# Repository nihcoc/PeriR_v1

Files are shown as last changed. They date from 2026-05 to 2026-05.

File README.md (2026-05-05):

# PeriR

A custom Software Defined Radio (SDR) carrier board built around the **Xilinx Zynq-7020 SoC** and **Analog Devices AD9364** RF transceiver. The board is designed to run **Kuiper Linux** (Analog Devices' Raspberry Pi OS-based distro) out of the box, with native support for GNU Radio and SDR++ applications.

---

## Overview

This project is inspired by the [FreeSRP](http://electronics.kitchen/misc/freesrp/) open-source SDR by Lukas Lao Beyer and borrows design references from the **FMCOMMS4**, **Zedboard**, **ADRV9364-Z7020**, and **PlutoSDR**.

The goal is a powerful, Linux-capable SDR transceiver with a compact form factor and eventually, a handheld device like the HackRF Portapack.

---

## Key Specifications

| Feature | Detail |
|---|---|
| **SoC / FPGA** | Xilinx Zynq-7020 (ARM Cortex-A9, ~85K LUTs) |
| **RF Transceiver** | Analog Devices AD9364 |
| **Frequency Range** | 70 MHz – 6.0 GHz |
| **Bandwidth** | 200 kHz – 56 MHz |
| **RAM** | 2× 128MB DDR3 (256MB total, Zedboard config) |
| **OS** | Kuiper Linux (Analog Devices / Raspberry Pi OS based) |
| **Primary Storage** | MicroSD card |

---

## Block Diagram

```
Antenna
   │
   ▼
AD9364 RF Transceiver (70MHz–6GHz)
   │  LVDS (max throughput)
   ▼
Zynq-7020 (PS + PL)
   ├── ARM Cortex-A9 (PS) ──► DDR3 RAM, SD Card, USB-OTG, Ethernet, HDMI
```

---

## Hardware Design

### RF Transceiver — AD9364
- **Signalling standard:** LVDS (chosen over CMOS for lower EMI and higher throughput)
- **Interface:** Connected to FPGA Bank 34 (VCCO = 2.5V, `LVDS_25` standard)
- **Balun:** TCM1-63AX+ wideband RF transformer (≤1.8 dB insertion loss @ 6 GHz)
- **Clock:** 40 MHz, 10 pF load capacitance (tested reference from AD)
- **Power rail:** 1.3V via ADP1754ACPZ-1.3-R7 (AD-recommended for stability)
- **TX Power Amp:** PGA-102 (dedicated clean 3.3V supply)

### Zynq-7020 SoC
- **PS Clock:** 33.33 MHz  
- **PL Clock:** 100 MHz (EPSON SG-8018CA oscillator)
- **Boot:** SD Card (primary), QSPI Flash (fallback)
- **Configuration:** Boot mode selectable via header pins/switches
- **RAM interface:** Signal lines terminated at 40 Ω

### Power Architecture

Power sequencing follows **DS187** requirements:
1. VCCPINT (1.0V)
2. VCCPAUX + VCCPLL (1.8V) — simultaneously
3. PS VCCO supplies: VCCOMIO0, VCCOMIO1, VCCO_DDR (3.3V / 1.5V / 0.75V)

| Rail | IC | Current | Usage |
|---|---|---|---|
| 1.0V | TPS62130A | 3A | Zynq VCCINT, VCCBRAM |
| 1.8V | TPS62130A | 3A | Zynq VCCAUX, VCCADC, MIO logic |
| 3.3V | TPS65251-3RHAR (Ch1) | 3A | I/O, SD card, interfaces |
| 2.5V | TPS65251-3RHAR (Ch2) | 2A | FPGA Bank 34 (LVDS) |
| 1.5V | TPS65251-3RHAR (Ch3) | 2A | DDR3 VCCIO |
| 0.75V | MAX1510ETB+ | — | DDR3 VTT termination |
| 1.3V | ADP1754ACPZ-1.3-R7 | — | AD9364 primary supply |
| 5V | External connector | — | Board input power |

> Sequencing is managed using EN (Enable) and PG (Power Good) pins chained between power ICs.
> AD7291BCPZ added for full-board power monitoring.

### Interfaces

| Interface | IC / Notes |
|---|---|
| **HDMI** | ADV7511 transmitter — follows Zedboard design for Kuiper Linux compatibility |
| **USB-OTG** | Standard USB 2.0 OTG with ESD protection |
| **Ethernet** | GbE — backup interface for setup and testing |
| **SD Card** | Level-shifted (1.8V MIO → 3.3V SD logic) |
| **QSPI Flash** | MT25QU128ABA — 128Mb, all data lines active |

## Software

- **OS:** [Kuiper Linux](https://wiki.analog.com/resources/tools-software/linux-software/kuiper-linux) by Analog Devices
- **SDR Applications:** GNU Radio, SDR++
- **FPGA toolchain:** Xilinx Vivado + Analog Devices HDL reference designs
- **Reference HDL:** [Analog Devices HDL](https://github.com/analogdevicesinc/hdl) (FMCOMMS4 / ADRV9364 compatible)

---

## Design References

- [FreeSRP](http://electronics.kitchen/misc/freesrp/) — Lukas Lao Beyer
- Analog Devices FMCOMMS4
- Xilinx Zedboard
- ADRV9364-Z7020
- PlutoSDR
- **Key Datasheets:** UG585, UG933, UG482, UG470, UG483, DS187, AD9364 Reference Manual

---

## Project Status

- [x] Component selection
- [x] Schematic capture
- [x] Footprint assignment
- [x] Schematic verification (round 1)
- [ ] Schematic verification (round 2)
- [ ] PCB layout & routing
- [ ] DFM review
- [ ] Fabrication & assembly
- [ ] Bring-up & firmware development
- [ ] HAT board design

---

*This is a personal learning project. Feedback and suggestions welcome — especially on the RF and LVDS sections!*

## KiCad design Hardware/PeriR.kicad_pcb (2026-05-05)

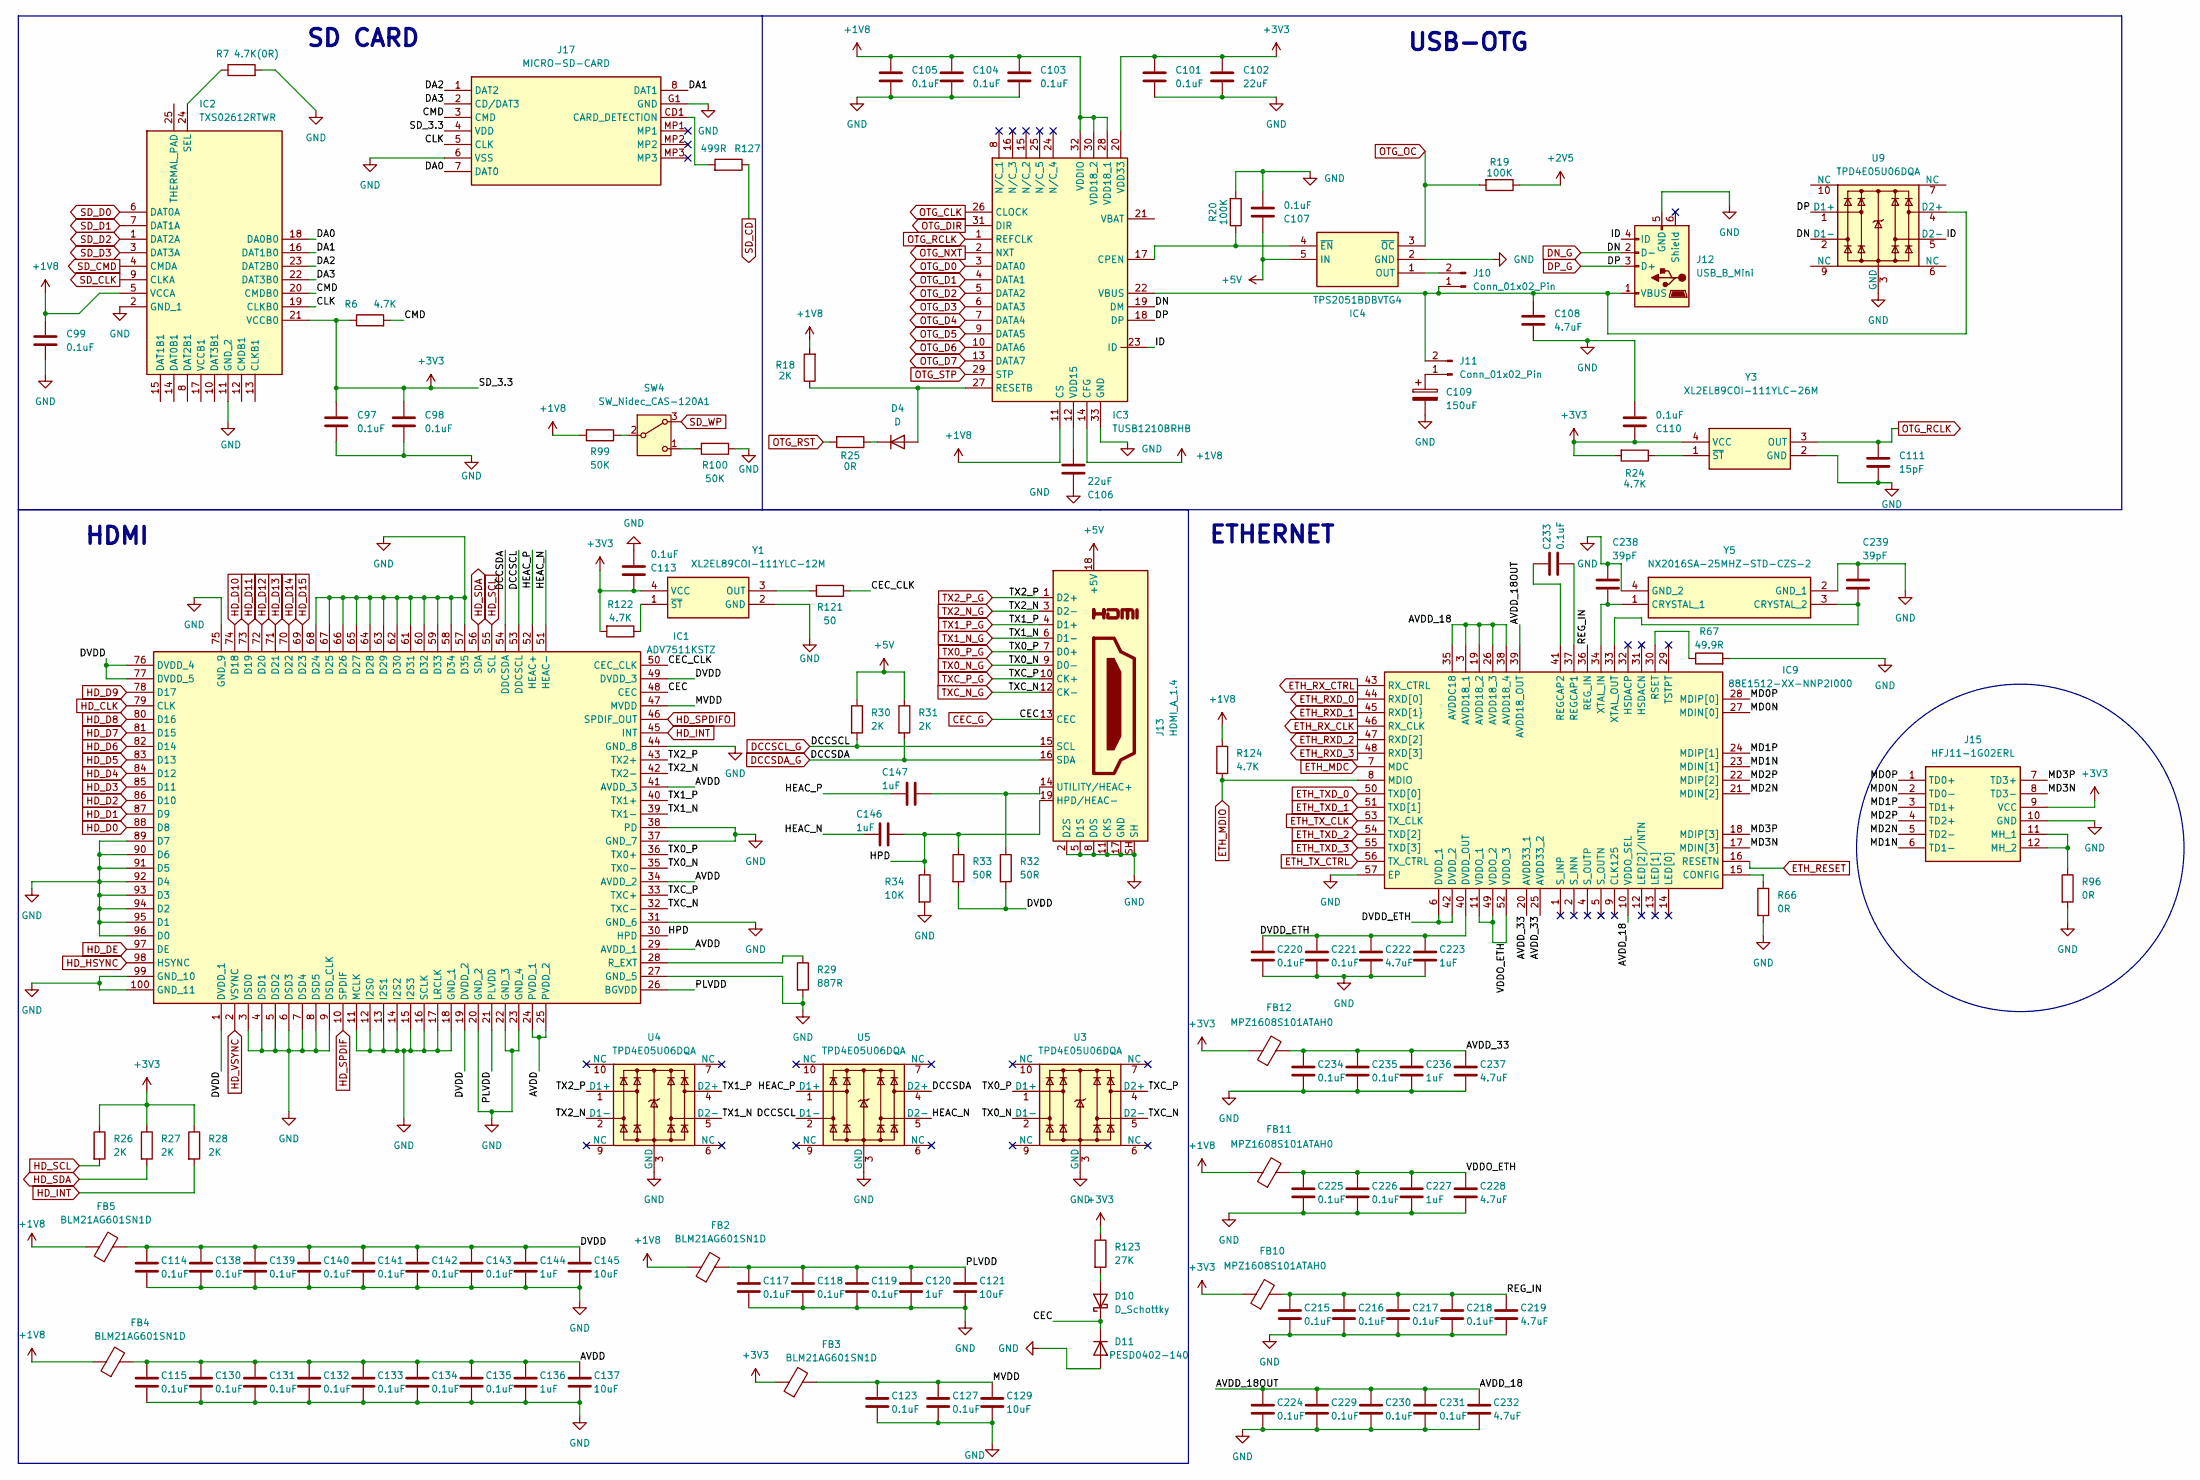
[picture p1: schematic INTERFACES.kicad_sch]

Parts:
C97, C98, C99, C101, C103, C104, C105, C107, C110, C113, C114, C115, C117, C118, C119, C123, C127, C130, C131, C132, C133, C134, C135, C138, C139, C140, C141, C142, C143, C215, C216, C217, C218, C220, C221, C224, C225, C226, C229, C230, C231, C233, C234, C235: 0.1uF; C_0402_1005Metric
C102, C106: 22uF; C_0603_1608Metric
C108, C219, C222, C228, C232, C237: 4.7uF; C_0603_1608Metric
C109: 150uF; CP_EIA-7343-31_Kemet-D
C111: 15pF; C_0201_0603Metric
C120, C136, C144, C146, C147, C223, C227, C236: 1uF; C_0603_1608Metric
C121, C129, C137, C145: 10uF; C_0603_1608Metric
C238, C239: 39pF; C_0201_0603Metric
D4: D; D_0805_2012Metric
D10: D_Schottky; D_0805_2012Metric
D11: PESD0402-140; D_0402_1005Metric
FB2, FB3, FB4, FB5: BLM21AG601SN1D; L_0603_1608Metric
FB10, FB11, FB12: MPZ1608S101ATAH0; L_0603_1608Metric
IC1: ADV7511KSTZ; QFP50P1600X1600X160-100N; Manufacturer_Part_Number ADV7511KSTZ; Mouser Part Number 584-ADV7511KSTZ
IC2: TXS02612RTWR; QFN50P400X400X80-25N-D; Manufacturer_Part_Number TXS02612RTWR; Mouser Part Number 595-TXS02612RTWR
IC3: TUSB1210BRHB; QFN50P500X500X100-33N-D; Manufacturer_Part_Number TUSB1210BRHB; Mouser Part Number 595-TUSB1210BRHB
IC4: TPS2051BDBVTG4; SOT95P280X145-5N; Manufacturer_Part_Number TPS2051BDBVTG4; Mouser Part Number 595-TPS2051BDBVTG4
IC9: 88E1512-XX-NNP2I000; QFN50P800X800X100-57N-D; Manufacturer_Part_Number 88E1512-XX-NNP2I000
J10, J11: Conn_01x02_Pin; PinSocket_1x02_P2.54mm_Vertical
J12: USB_B_Mini; USB_Mini-B_Wuerth_65100516121_Horizontal
J13: HDMI_A_1.4; HDMI_A_Molex_208658-1001_Horizontal
J15: HFJ11-1G02ERL; HFJ111G02ERL; Manufacturer_Part_Number HFJ11-1G02ERL; Mouser Part Number 493-HFJ11-1G02ERL
J17: MICRO-SD-CARD; MICROSDCARD; Manufacturer_Part_Number MICRO-SD-CARD; Mouser Part Number N/A
R6, R24, R122, R124: 4.7K; R_0402_1005Metric
R7: 4.7K(0R); R_0402_1005Metric
R18, R26, R27, R28, R30, R31: 2K; R_0402_1005Metric
R19, R20: 100K; R_0402_1005Metric
R25, R66, R96: 0R; R_0402_1005Metric
R29: 887R; R_0402_1005Metric
R32, R33: 50R; R_0402_1005Metric
R34: 10K; R_0402_1005Metric
R67: 49.9R; R_0402_1005Metric
R99, R100: 50K; R_0402_1005Metric
R121: 50; R_0402_1005Metric
R123: 27K; R_0402_1005Metric
R127: 499R; R_0402_1005Metric
SW4: SW_Nidec_CAS-120A1; Nidec_Copal_CAS-120A
U3, U4, U5, U9: TPD4E05U06DQA; USON-10_2.5x1.0mm_P0.5mm
Y1: XL2EL89COI-111YLC-12M; SG8018CA1000000MTJHSA0; Manufacturer_Part_Number SG-8018CA 100.0000M-TJHSA0
Y3: XL2EL89COI-111YLC-26M; SG8018CA1000000MTJHSA0; Manufacturer_Part_Number SG-8018CA 100.0000M-TJHSA0
Y5: NX2016SA-25MHZ-STD-CZS-2; FA128400000MF20XK; Mouser Part Number 732-FA-12840MF20X-K

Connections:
+1V8: C99.2, C103.2, C104.2, C105.2, FB2.1, FB4.1, FB5.1, FB11.1, IC2.5 (VCCA), IC3.11 (CS), IC3.14 (CFG), IC3.28 (VDD18_1), IC3.30 (VDD18_2), IC3.32 (VDDIO), R18.2, R99.2, R124.1; also elsewhere on the board
+5V: C107.2, IC4.5 (IN), J13.18 (+5V), R30.1, R31.1; also elsewhere on the board
/INTERFACES/AVDD: C115.2, C130.2, C131.2, C132.2, C133.2, C134.2, C135.2, C136.2, C137.2, FB4.2, IC1.24 (PVDD_1), IC1.25 (PVDD_2), IC1.29 (AVDD_1), IC1.34 (AVDD_2), IC1.41 (AVDD_3)
/INTERFACES/AVDD_18: C224.2, C229.2, C230.2, C231.2, C232.2, IC9.3 (AVDD18_1), IC9.10 (VDDO_SEL), IC9.19 (AVDD18_2), IC9.26 (AVDD18_3), IC9.35 (AVDDC18), IC9.38 (AVDD18_4), IC9.39 (AVDD18_OUT)
/INTERFACES/AVDD_33: C234.2, C235.2, C236.2, C237.2, FB12.2, IC9.20 (AVDD33_1), IC9.25 (AVDD33_2)
/INTERFACES/CEC_CLK: IC1.50 (CEC_CLK), R121.1
/INTERFACES/CLK: IC2.19 (CLKB0), J17.5 (CLK)
/INTERFACES/CMD: IC2.20 (CMDB0), J17.3 (CMD), R6.2
/INTERFACES/DA0: IC2.18 (DA0B0), J17.7 (DAT0)
/INTERFACES/DA1: IC2.16 (DAT1B0), J17.8 (DAT1)
/INTERFACES/DA2: IC2.23 (DAT2B0), J17.1 (DAT2)
/INTERFACES/DA3: IC2.22 (DAT3B0), J17.2 (CD/DAT3)
/INTERFACES/DVDD: C114.2, C138.2, C139.2, C140.2, C141.2, C142.2, C143.2, C144.2, C145.2, FB5.2, IC1.1 (DVDD_1), IC1.19 (DVDD_2), IC1.49 (DVDD_3), IC1.76 (DVDD_4), IC1.77 (DVDD_5), R32.2, R33.2
/INTERFACES/DVDD_ETH: C220.2, C221.2, C222.2, C223.2, IC9.6 (DVDD_1), IC9.40 (DVDD_OUT), IC9.42 (DVDD_2)
/INTERFACES/HEAC_N: C146.2, IC1.51 (HEAC-), U5.5 (D2-)
/INTERFACES/HEAC_P: C147.2, IC1.52 (HEAC+), U5.1 (D1+)
/INTERFACES/HPD: C146.1, IC1.30 (HPD), J13.19 (HPD/HEAC-), R33.1, R34.1
/INTERFACES/ID: IC3.23 (ID), J12.4 (ID), U9.5 (D2-)
/INTERFACES/MD0N: IC9.27 (MDIN[0]), J15.2 (TD0-)
/INTERFACES/MD0P: IC9.28 (MDIP[0]), J15.1 (TD0+)
/INTERFACES/MD1N: IC9.23 (MDIN[1]), J15.6 (TD1-)
/INTERFACES/MD1P: IC9.24 (MDIP[1]), J15.3 (TD1+)
/INTERFACES/MD2N: IC9.21 (MDIN[2]), J15.5 (TD2-)
/INTERFACES/MD2P: IC9.22 (MDIP[2]), J15.4 (TD2+)
/INTERFACES/MD3N: IC9.17 (MDIN[3]), J15.8 (TD3-)
/INTERFACES/MD3P: IC9.18 (MDIP[3]), J15.7 (TD3+)
/INTERFACES/MVDD: C123.2, C127.2, C129.2, FB3.2, IC1.47 (MVDD); also elsewhere on the board
/INTERFACES/PLVDD: C117.2, C118.2, C119.2, C120.2, C121.2, FB2.2, IC1.21 (PLVDD), IC1.26 (BGVDD)
/INTERFACES/REG_IN: C215.2, C216.2, C217.2, C218.2, C219.2, FB10.2, IC9.36 (REG_IN)
/INTERFACES/VDDO_ETH: C225.2, C226.2, C227.2, C228.2, FB11.2, IC9.11 (VDDO_1), IC9.49 (VDDO_2), IC9.52 (VDDO_3)
CEC_G: D10.1 (K), D11.1 (K), IC1.48 (CEC), J13.13 (CEC)
DCCSCL_G: IC1.53 (DDCSCL), J13.15 (SCL), R30.2, U5.2 (D1-)
DCCSDA_G: IC1.54 (DDCSDA), J13.16 (SDA), R31.2, U5.4 (D2+)
DN_G: IC3.19 (DM), J12.2 (D-), U9.2 (D1-)
DP_G: IC3.18 (DP), J12.3 (D+), U9.1 (D1+)
ETH_MDC: IC9.7 (MDC); also elsewhere on the board
ETH_MDIO: IC9.8 (MDIO), R124.2; also elsewhere on the board
ETH_RESET: IC9.16 (RESETN); also elsewhere on the board
ETH_RXD_0: IC9.44 (RXD[0]); also elsewhere on the board
ETH_RXD_1: IC9.45 (RXD[1}); also elsewhere on the board
ETH_RXD_2: IC9.47 (RXD[2]); also elsewhere on the board
ETH_RXD_3: IC9.48 (RXD[3]); also elsewhere on the board
ETH_RX_CLK: IC9.46 (RX_CLK); also elsewhere on the board
ETH_RX_CTRL: IC9.43 (RX_CTRL); also elsewhere on the board
ETH_TXD_0: IC9.50 (TXD[0]); also elsewhere on the board
ETH_TXD_1: IC9.51 (TXD[1]); also elsewhere on the board
ETH_TXD_2: IC9.54 (TXD[2]); also elsewhere on the board
ETH_TXD_3: IC9.55 (TXD[3]); also elsewhere on the board
ETH_TX_CLK: IC9.53 (TX_CLK); also elsewhere on the board
ETH_TX_CTRL: IC9.56 (TX_CTRL); also elsewhere on the board
HD_CLK: IC1.79 (CLK); also elsewhere on the board
HD_D0: IC1.88 (D8); also elsewhere on the board
HD_D1: IC1.87 (D9); also elsewhere on the board
HD_D2: IC1.86 (D10); also elsewhere on the board
HD_D3: IC1.85 (D11); also elsewhere on the board
HD_D4: IC1.84 (D12); also elsewhere on the board
HD_D5: IC1.83 (D13); also elsewhere on the board
HD_D6: IC1.82 (D14); also elsewhere on the board
HD_D7: IC1.81 (D15); also elsewhere on the board
HD_D8: IC1.80 (D16); also elsewhere on the board
HD_D9: IC1.78 (D17); also elsewhere on the board
HD_D10: IC1.74 (D18); also elsewhere on the board
HD_D11: IC1.73 (D19); also elsewhere on the board
HD_D12: IC1.72 (D20); also elsewhere on the board
HD_D13: IC1.71 (D21); also elsewhere on the board
HD_D14: IC1.70 (D22); also elsewhere on the board
HD_D15: IC1.69 (D23); also elsewhere on the board
HD_DE: IC1.97 (DE); also elsewhere on the board
HD_HSYNC: IC1.98 (HSYNC); also elsewhere on the board
HD_INT: IC1.45 (INT), R28.2; also elsewhere on the board
HD_SCL: IC1.55 (SCL), R26.2; also elsewhere on the board
HD_SDA: IC1.56 (SDA), R27.2; also elsewhere on the board
HD_SPDIF: IC1.10 (SPDIF); also elsewhere on the board
HD_SPDIFO: IC1.46 (SPDIF_OUT); also elsewhere on the board
HD_VSYNC: IC1.2 (VSYNC); also elsewhere on the board
unnamed: D4.2 (A), IC3.27 (RESETB), R18.1
unnamed: D4.1 (K), R25.1
unnamed: D10.2 (A), R123.2
unnamed: IC1.28 (R_EXT), R29.1
unnamed: IC2.24 (SEL), R7.1
unnamed: IC3.17 (CPEN), IC4.4 (~EN), R20.1
unnamed: C108.1, IC3.22 (VBUS), J10.1, J11.2, J12.1 (VBUS), U9.4 (D2+)
unnamed: C106.1, IC3.12 (VDD15)
unnamed: IC4.1 (OUT), J10.2
unnamed: IC9.15 (CONFIG), R66.1
unnamed: C233.1, IC9.37 (REGCAP1)
unnamed: C233.2, IC9.41 (REGCAP2)
unnamed: IC9.30 (RSET), R67.1
unnamed: C238.1, IC9.34 (XTAL_IN), Y5.1 (CRYSTAL_1)
unnamed: C239.1, IC9.33 (XTAL_OUT), Y5.3 (CRYSTAL_2)
unnamed: C109.1, J11.1
unnamed: C147.1, J13.14 (UTILITY/HEAC+), R32.1
unnamed: J15.11 (MH_1), J15.12 (MH_2), R96.1
unnamed: J17.CD1 (CARD_DETECTION), R127.2
unnamed: R99.1, SW4.2 (B)
unnamed: R100.2, SW4.1 (C)
unnamed: R121.2, Y1.3 (OUT)
unnamed: R122.1, Y1.1 (~ST)
unnamed: R24.1, Y3.1 (~ST)
OTG_CLK: IC3.26 (CLOCK); also elsewhere on the board
OTG_D0: IC3.3 (DATA0); also elsewhere on the board
OTG_D1: IC3.4 (DATA1); also elsewhere on the board
OTG_D2: IC3.5 (DATA2); also elsewhere on the board
OTG_D3: IC3.6 (DATA3); also elsewhere on the board
OTG_D4: IC3.7 (DATA4); also elsewhere on the board
OTG_D5: IC3.9 (DATA5); also elsewhere on the board
OTG_D6: IC3.10 (DATA6); also elsewhere on the board
OTG_D7: IC3.13 (DATA7); also elsewhere on the board
OTG_DIR: IC3.31 (DIR); also elsewhere on the board
OTG_NXT: IC3.2 (NXT); also elsewhere on the board
OTG_OC: IC4.3 (~OC), R19.2; also elsewhere on the board
OTG_RCLK: C111.1, IC3.1 (REFCLK), Y3.3 (OUT)
OTG_RST: R25.2; also elsewhere on the board
OTG_STP: IC3.29 (STP); also elsewhere on the board
SD_CD: R127.1; also elsewhere on the board
SD_CLK: IC2.9 (CLKA); also elsewhere on the board
SD_CMD: IC2.4 (CMDA); also elsewhere on the board
SD_D0: IC2.6 (DAT0A); also elsewhere on the board
SD_D1: IC2.7 (DAT1A); also elsewhere on the board
SD_D2: IC2.1 (DAT2A); also elsewhere on the board
SD_D3: IC2.3 (DAT3A); also elsewhere on the board
SD_WP: SW4.3 (A); also elsewhere on the board
TX0_N_G: IC1.35 (TX0-), J13.9 (D0-), U3.2 (D1-)
TX0_P_G: IC1.36 (TX0+), J13.7 (D0+), U3.1 (D1+)
TX1_N_G: IC1.39 (TX1-), J13.6 (D1-), U4.5 (D2-)
TX1_P_G: IC1.40 (TX1+), J13.4 (D1+), U4.4 (D2+)
TX2_N_G: IC1.42 (TX2-), J13.3 (D2-), U4.2 (D1-)
TX2_P_G: IC1.43 (TX2+), J13.1 (D2+), U4.1 (D1+)
TXC_N_G: IC1.32 (TXC-), J13.12 (CK-), U3.5 (D2-)
TXC_P_G: IC1.33 (TXC+), J13.10 (CK+), U3.4 (D2+)

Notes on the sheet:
SD CARD
USB-OTG
ETHERNET
HDMI

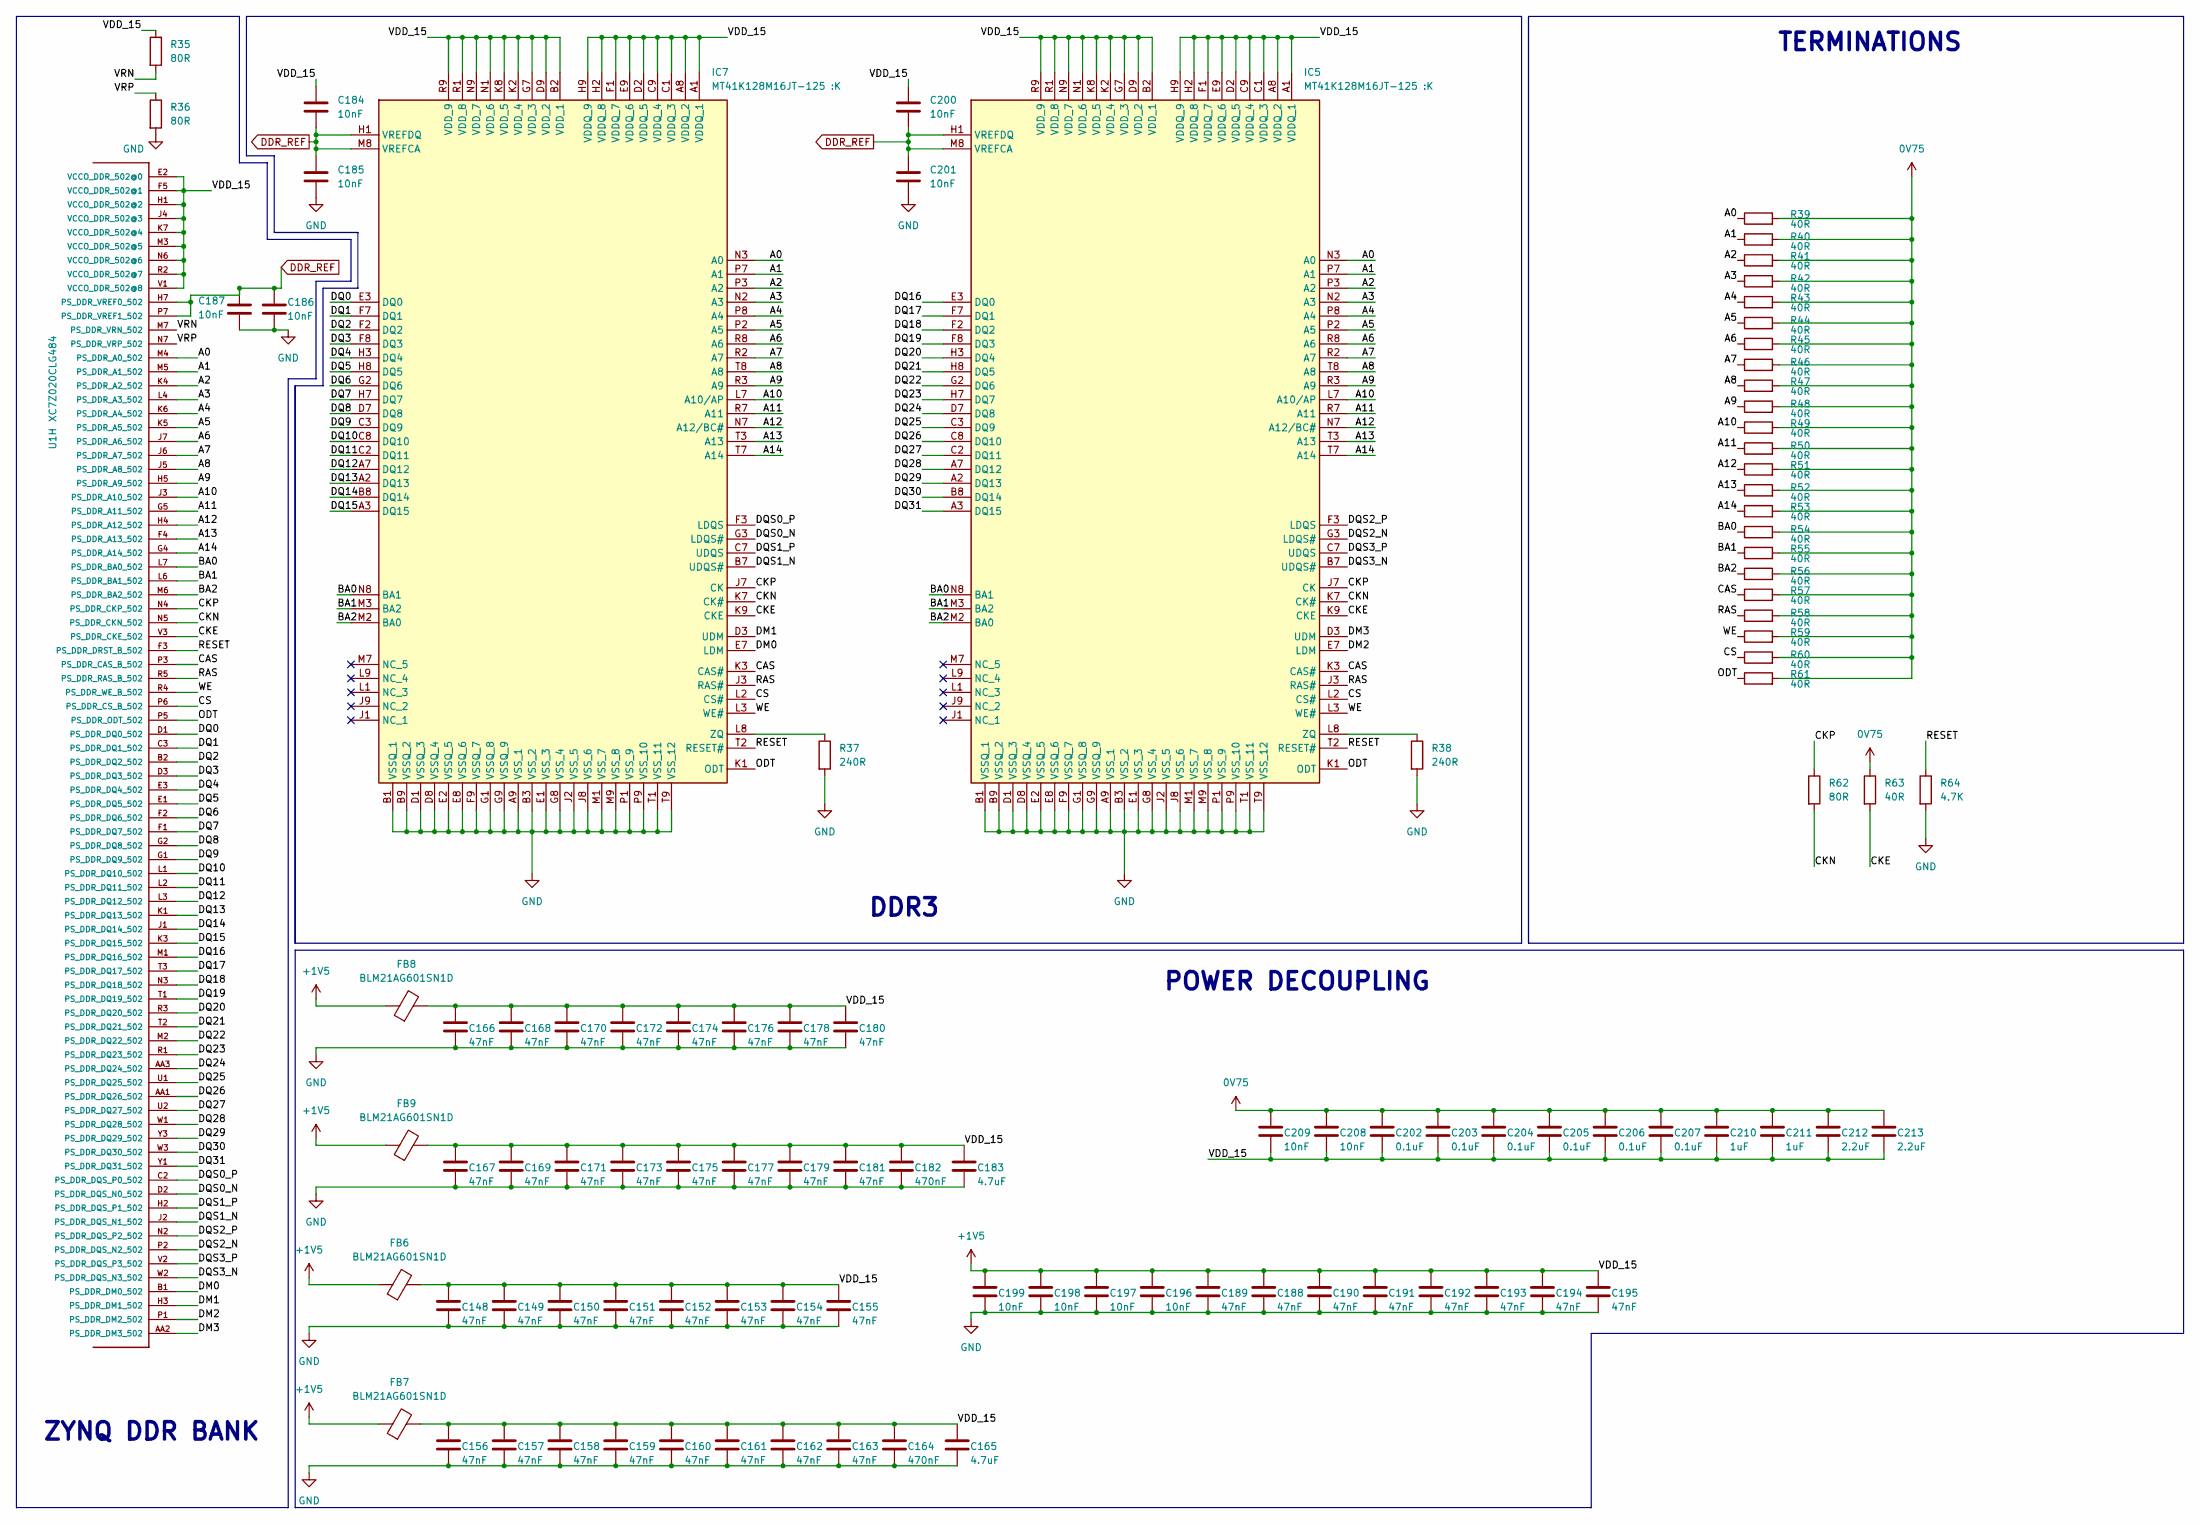
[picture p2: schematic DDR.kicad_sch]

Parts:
C148, C149, C150, C151, C152, C153, C154, C155, C156, C157, C158, C159, C160, C161, C162, C163, C166, C167, C168, C169, C170, C171, C172, C173, C174, C175, C176, C177, C178, C179, C180, C181, C188, C189, C190, C191, C192, C193, C194, C195: 47nF; C_0201_0603Metric
C164: 470nF; C_0402_1005Metric
C165, C183: 4.7uF; C_0603_1608Metric
C182: 470nF; C_0201_0603Metric
C184, C185, C186, C187, C196, C197, C198, C199, C200, C201: 10nF; C_0201_0603Metric
C202, C203, C204, C205, C206, C207: 0.1uF; C_0402_1005Metric
C208, C209: 10nF; C_0603_1608Metric
C210, C211: 1uF; C_0603_1608Metric
C212, C213: 2.2uF; C_0603_1608Metric
FB6, FB7, FB8, FB9: BLM21AG601SN1D; L_0603_1608Metric
IC5, IC7: MT41K128M16JT-125 :K; BGA96C80P9X16_800X1400X120; Manufacturer_Part_Number MT41K128M16JT-125
R35, R36, R62: 80R; R_0402_1005Metric
R37, R38: 240R; R_0402_1005Metric
R39, R40, R41, R42, R43, R44, R45, R46, R47, R48, R49, R50, R51, R52, R53, R54, R55, R56, R57, R58, R59, R60, R61, R63: 40R; R_0402_1005Metric
R64: 4.7K; R_0402_1005Metric
U1: XC7Z020CLG484; CS484

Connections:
0V75: C202.1, C203.1, C204.1, C205.1, C206.1, C207.1, C208.1, C209.1, C210.1, C211.1, C212.1, C213.1, R39.2, R40.2, R41.2, R42.2, R43.2, R44.2, R45.2, R46.2, R47.2, R48.2, R49.2, R50.2, R51.2, R52.2, R53.2, R54.2, R55.2, R56.2, R57.2, R58.2, R59.2, R60.2, R61.2, R63.1; also elsewhere on the board
+1V5: C148.1, C149.1, C150.1, C151.1, C152.1, C153.1, C154.1, C155.1, C156.1, C157.1, C158.1, C159.1, C160.1, C161.1, C162.1, C163.1, C164.1, C165.1, C166.1, C167.1, C168.1, C169.1, C170.1, C171.1, C172.1, C173.1, C174.1, C175.1, C176.1, C177.1, C178.1, C179.1, C180.1, C181.1, C182.1, C183.1, C184.1, C188.1, C189.1, C190.1, C191.1, C192.1, C193.1, C194.1, C195.1, C196.1, C197.1, C198.1, C199.1, C200.1, C202.2, C203.2, C204.2, C205.2, C206.2, C207.2, C208.2, C209.2, C210.2, C211.2, C212.2, C213.2, FB6.1, FB6.2, FB7.1, FB7.2, FB8.1, FB8.2, FB9.1, FB9.2, IC5.A1 (VDDQ_1), IC5.A8 (VDDQ_2), IC5.B2 (VDD_1), IC5.C1 (VDDQ_3), IC5.C9 (VDDQ_4), IC5.D2 (VDDQ_5), IC5.D9 (VDD_2), IC5.E9 (VDDQ_6), IC5.F1 (VDDQ_7), IC5.G7 (VDD_3), IC5.H2 (VDDQ_8), IC5.H9 (VDDQ_9), IC5.K2 (VDD_4), IC5.K8 (VDD_5), IC5.N1 (VDD_6), IC5.N9 (VDD_7), IC5.R1 (VDD_8), IC5.R9 (VDD_9), IC7.A1 (VDDQ_1), IC7.A8 (VDDQ_2), IC7.B2 (VDD_1), IC7.C1 (VDDQ_3), IC7.C9 (VDDQ_4), IC7.D2 (VDDQ_5), IC7.D9 (VDD_2), IC7.E9 (VDDQ_6), IC7.F1 (VDDQ_7), IC7.G7 (VDD_3), IC7.H2 (VDDQ_8), IC7.H9 (VDDQ_9), IC7.K2 (VDD_4), IC7.K8 (VDD_5), IC7.N1 (VDD_6), IC7.N9 (VDD_7), IC7.R1 (VDD_8), IC7.R9 (VDD_9), R35.1, U1.E2 (VCCO_DDR_502@0), U1.F5 (VCCO_DDR_502@1), U1.H1 (VCCO_DDR_502@2), U1.J4 (VCCO_DDR_502@3), U1.K7 (VCCO_DDR_502@4), U1.M3 (VCCO_DDR_502@5), U1.N6 (VCCO_DDR_502@6), U1.R2 (VCCO_DDR_502@7), U1.V1 (VCCO_DDR_502@8); also elsewhere on the board
/DDR/A0: IC5.N3 (A0), IC7.N3 (A0), R39.1, U1.M4 (PS_DDR_A0_502)
/DDR/A1: IC5.P7 (A1), IC7.P7 (A1), R40.1, U1.M5 (PS_DDR_A1_502)
/DDR/A2: IC5.P3 (A2), IC7.P3 (A2), R41.1, U1.K4 (PS_DDR_A2_502)
/DDR/A3: IC5.N2 (A3), IC7.N2 (A3), R42.1, U1.L4 (PS_DDR_A3_502)
/DDR/A4: IC5.P8 (A4), IC7.P8 (A4), R43.1, U1.K6 (PS_DDR_A4_502)
/DDR/A5: IC5.P2 (A5), IC7.P2 (A5), R44.1, U1.K5 (PS_DDR_A5_502)
/DDR/A6: IC5.R8 (A6), IC7.R8 (A6), R45.1, U1.J7 (PS_DDR_A6_502)
/DDR/A7: IC5.R2 (A7), IC7.R2 (A7), R46.1, U1.J6 (PS_DDR_A7_502)
/DDR/A8: IC5.T8 (A8), IC7.T8 (A8), R47.1, U1.J5 (PS_DDR_A8_502)
/DDR/A9: IC5.R3 (A9), IC7.R3 (A9), R48.1, U1.H5 (PS_DDR_A9_502)
/DDR/A10: IC5.L7 (A10/AP), IC7.L7 (A10/AP), R49.1, U1.J3 (PS_DDR_A10_502)
/DDR/A11: IC5.R7 (A11), IC7.R7 (A11), R50.1, U1.G5 (PS_DDR_A11_502)
/DDR/A12: IC5.N7 (A12/BC#), IC7.N7 (A12/BC#), R51.1, U1.H4 (PS_DDR_A12_502)
/DDR/A13: IC5.T3 (A13), IC7.T3 (A13), R52.1, U1.F4 (PS_DDR_A13_502)
/DDR/A14: IC5.T7 (A14), IC7.T7 (A14), R53.1, U1.G4 (PS_DDR_A14_502)
/DDR/BA0: IC5.N8 (BA1), IC7.N8 (BA1), R54.1, U1.L7 (PS_DDR_BA0_502)
/DDR/BA1: IC5.M3 (BA2), IC7.M3 (BA2), R55.1, U1.L6 (PS_DDR_BA1_502)
/DDR/BA2: IC5.M2 (BA0), IC7.M2 (BA0), R56.1, U1.M6 (PS_DDR_BA2_502)
/DDR/CAS: IC5.K3 (CAS#), IC7.K3 (CAS#), R57.1, U1.P3 (PS_DDR_CAS_B_502)
/DDR/CKE: IC5.K9 (CKE), IC7.K9 (CKE), R63.2, U1.V3 (PS_DDR_CKE_502)
/DDR/CKN: IC5.K7 (CK#), IC7.K7 (CK#), R62.2, U1.N5 (PS_DDR_CKN_502)
/DDR/CKP: IC5.J7 (CK), IC7.J7 (CK), R62.1, U1.N4 (PS_DDR_CKP_502)
/DDR/CS: IC5.L2 (CS#), IC7.L2 (CS#), R60.1, U1.P6 (PS_DDR_CS_B_502)
/DDR/DM0: IC7.E7 (LDM), U1.B1 (PS_DDR_DM0_502)
/DDR/DM1: IC7.D3 (UDM), U1.H3 (PS_DDR_DM1_502)
/DDR/DM2: IC5.E7 (LDM), U1.P1 (PS_DDR_DM2_502)
/DDR/DM3: IC5.D3 (UDM), U1.AA2 (PS_DDR_DM3_502)
/DDR/DQ0: IC7.E3 (DQ0), U1.D1 (PS_DDR_DQ0_502)
/DDR/DQ1: IC7.F7 (DQ1), U1.C3 (PS_DDR_DQ1_502)
/DDR/DQ2: IC7.F2 (DQ2), U1.B2 (PS_DDR_DQ2_502)
/DDR/DQ3: IC7.F8 (DQ3), U1.D3 (PS_DDR_DQ3_502)
/DDR/DQ4: IC7.H3 (DQ4), U1.E3 (PS_DDR_DQ4_502)
/DDR/DQ5: IC7.H8 (DQ5), U1.E1 (PS_DDR_DQ5_502)
/DDR/DQ6: IC7.G2 (DQ6), U1.F2 (PS_DDR_DQ6_502)
/DDR/DQ7: IC7.H7 (DQ7), U1.F1 (PS_DDR_DQ7_502)
/DDR/DQ8: IC7.D7 (DQ8), U1.G2 (PS_DDR_DQ8_502)
/DDR/DQ9: IC7.C3 (DQ9), U1.G1 (PS_DDR_DQ9_502)
/DDR/DQ10: IC7.C8 (DQ10), U1.L1 (PS_DDR_DQ10_502)
/DDR/DQ11: IC7.C2 (DQ11), U1.L2 (PS_DDR_DQ11_502)
/DDR/DQ12: IC7.A7 (DQ12), U1.L3 (PS_DDR_DQ12_502)
/DDR/DQ13: IC7.A2 (DQ13), U1.K1 (PS_DDR_DQ13_502)
/DDR/DQ14: IC7.B8 (DQ14), U1.J1 (PS_DDR_DQ14_502)
/DDR/DQ15: IC7.A3 (DQ15), U1.K3 (PS_DDR_DQ15_502)
/DDR/DQ16: IC5.E3 (DQ0), U1.M1 (PS_DDR_DQ16_502)
/DDR/DQ17: IC5.F7 (DQ1), U1.T3 (PS_DDR_DQ17_502)
/DDR/DQ18: IC5.F2 (DQ2), U1.N3 (PS_DDR_DQ18_502)
/DDR/DQ19: IC5.F8 (DQ3), U1.T1 (PS_DDR_DQ19_502)
/DDR/DQ20: IC5.H3 (DQ4), U1.R3 (PS_DDR_DQ20_502)
/DDR/DQ21: IC5.H8 (DQ5), U1.T2 (PS_DDR_DQ21_502)
/DDR/DQ22: IC5.G2 (DQ6), U1.M2 (PS_DDR_DQ22_502)
/DDR/DQ23: IC5.H7 (DQ7), U1.R1 (PS_DDR_DQ23_502)
/DDR/DQ24: IC5.D7 (DQ8), U1.AA3 (PS_DDR_DQ24_502)
/DDR/DQ25: IC5.C3 (DQ9), U1.U1 (PS_DDR_DQ25_502)
/DDR/DQ26: IC5.C8 (DQ10), U1.AA1 (PS_DDR_DQ26_502)
/DDR/DQ27: IC5.C2 (DQ11), U1.U2 (PS_DDR_DQ27_502)
/DDR/DQ28: IC5.A7 (DQ12), U1.W1 (PS_DDR_DQ28_502)
/DDR/DQ29: IC5.A2 (DQ13), U1.Y3 (PS_DDR_DQ29_502)
/DDR/DQ30: IC5.B8 (DQ14), U1.W3 (PS_DDR_DQ30_502)
/DDR/DQ31: IC5.A3 (DQ15), U1.Y1 (PS_DDR_DQ31_502)
/DDR/DQS0_N: IC7.G3 (LDQS#), U1.D2 (PS_DDR_DQS_N0_502)
/DDR/DQS0_P: IC7.F3 (LDQS), U1.C2 (PS_DDR_DQS_P0_502)
/DDR/DQS1_N: IC7.B7 (UDQS#), U1.J2 (PS_DDR_DQS_N1_502)
/DDR/DQS1_P: IC7.C7 (UDQS), U1.H2 (PS_DDR_DQS_P1_502)
/DDR/DQS2_N: IC5.G3 (LDQS#), U1.P2 (PS_DDR_DQS_N2_502)
/DDR/DQS2_P: IC5.F3 (LDQS), U1.N2 (PS_DDR_DQS_P2_502)
/DDR/DQS3_N: IC5.B7 (UDQS#), U1.W2 (PS_DDR_DQS_N3_502)
/DDR/DQS3_P: IC5.C7 (UDQS), U1.V2 (PS_DDR_DQS_P3_502)
/DDR/ODT: IC5.K1 (ODT), IC7.K1 (ODT), R61.1, U1.P5 (PS_DDR_ODT_502)
/DDR/RAS: IC5.J3 (RAS#), IC7.J3 (RAS#), R58.1, U1.R5 (PS_DDR_RAS_B_502)
/DDR/RESET: IC5.T2 (RESET#), IC7.T2 (RESET#), R64.1, U1.F3 (PS_DDR_DRST_B_502)
/DDR/VRN: R35.2, U1.M7 (PS_DDR_VRN_502)
/DDR/VRP: R36.1, U1.N7 (PS_DDR_VRP_502)
/DDR/WE: IC5.L3 (WE#), IC7.L3 (WE#), R59.1, U1.R4 (PS_DDR_WE_B_502)
DDR_REF: C184.2, C185.1, C186.1, C187.1, C200.2, C201.1, IC5.H1 (VREFDQ), IC5.M8 (VREFCA), IC7.H1 (VREFDQ), IC7.M8 (VREFCA), U1.H7 (PS_DDR_VREF0_502), U1.P7 (PS_DDR_VREF1_502); also elsewhere on the board
unnamed: IC5.L8 (ZQ), R38.1
unnamed: IC7.L8 (ZQ), R37.1

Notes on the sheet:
DDR3
POWER DECOUPLING
ZYNQ DDR BANK
TERMINATIONS

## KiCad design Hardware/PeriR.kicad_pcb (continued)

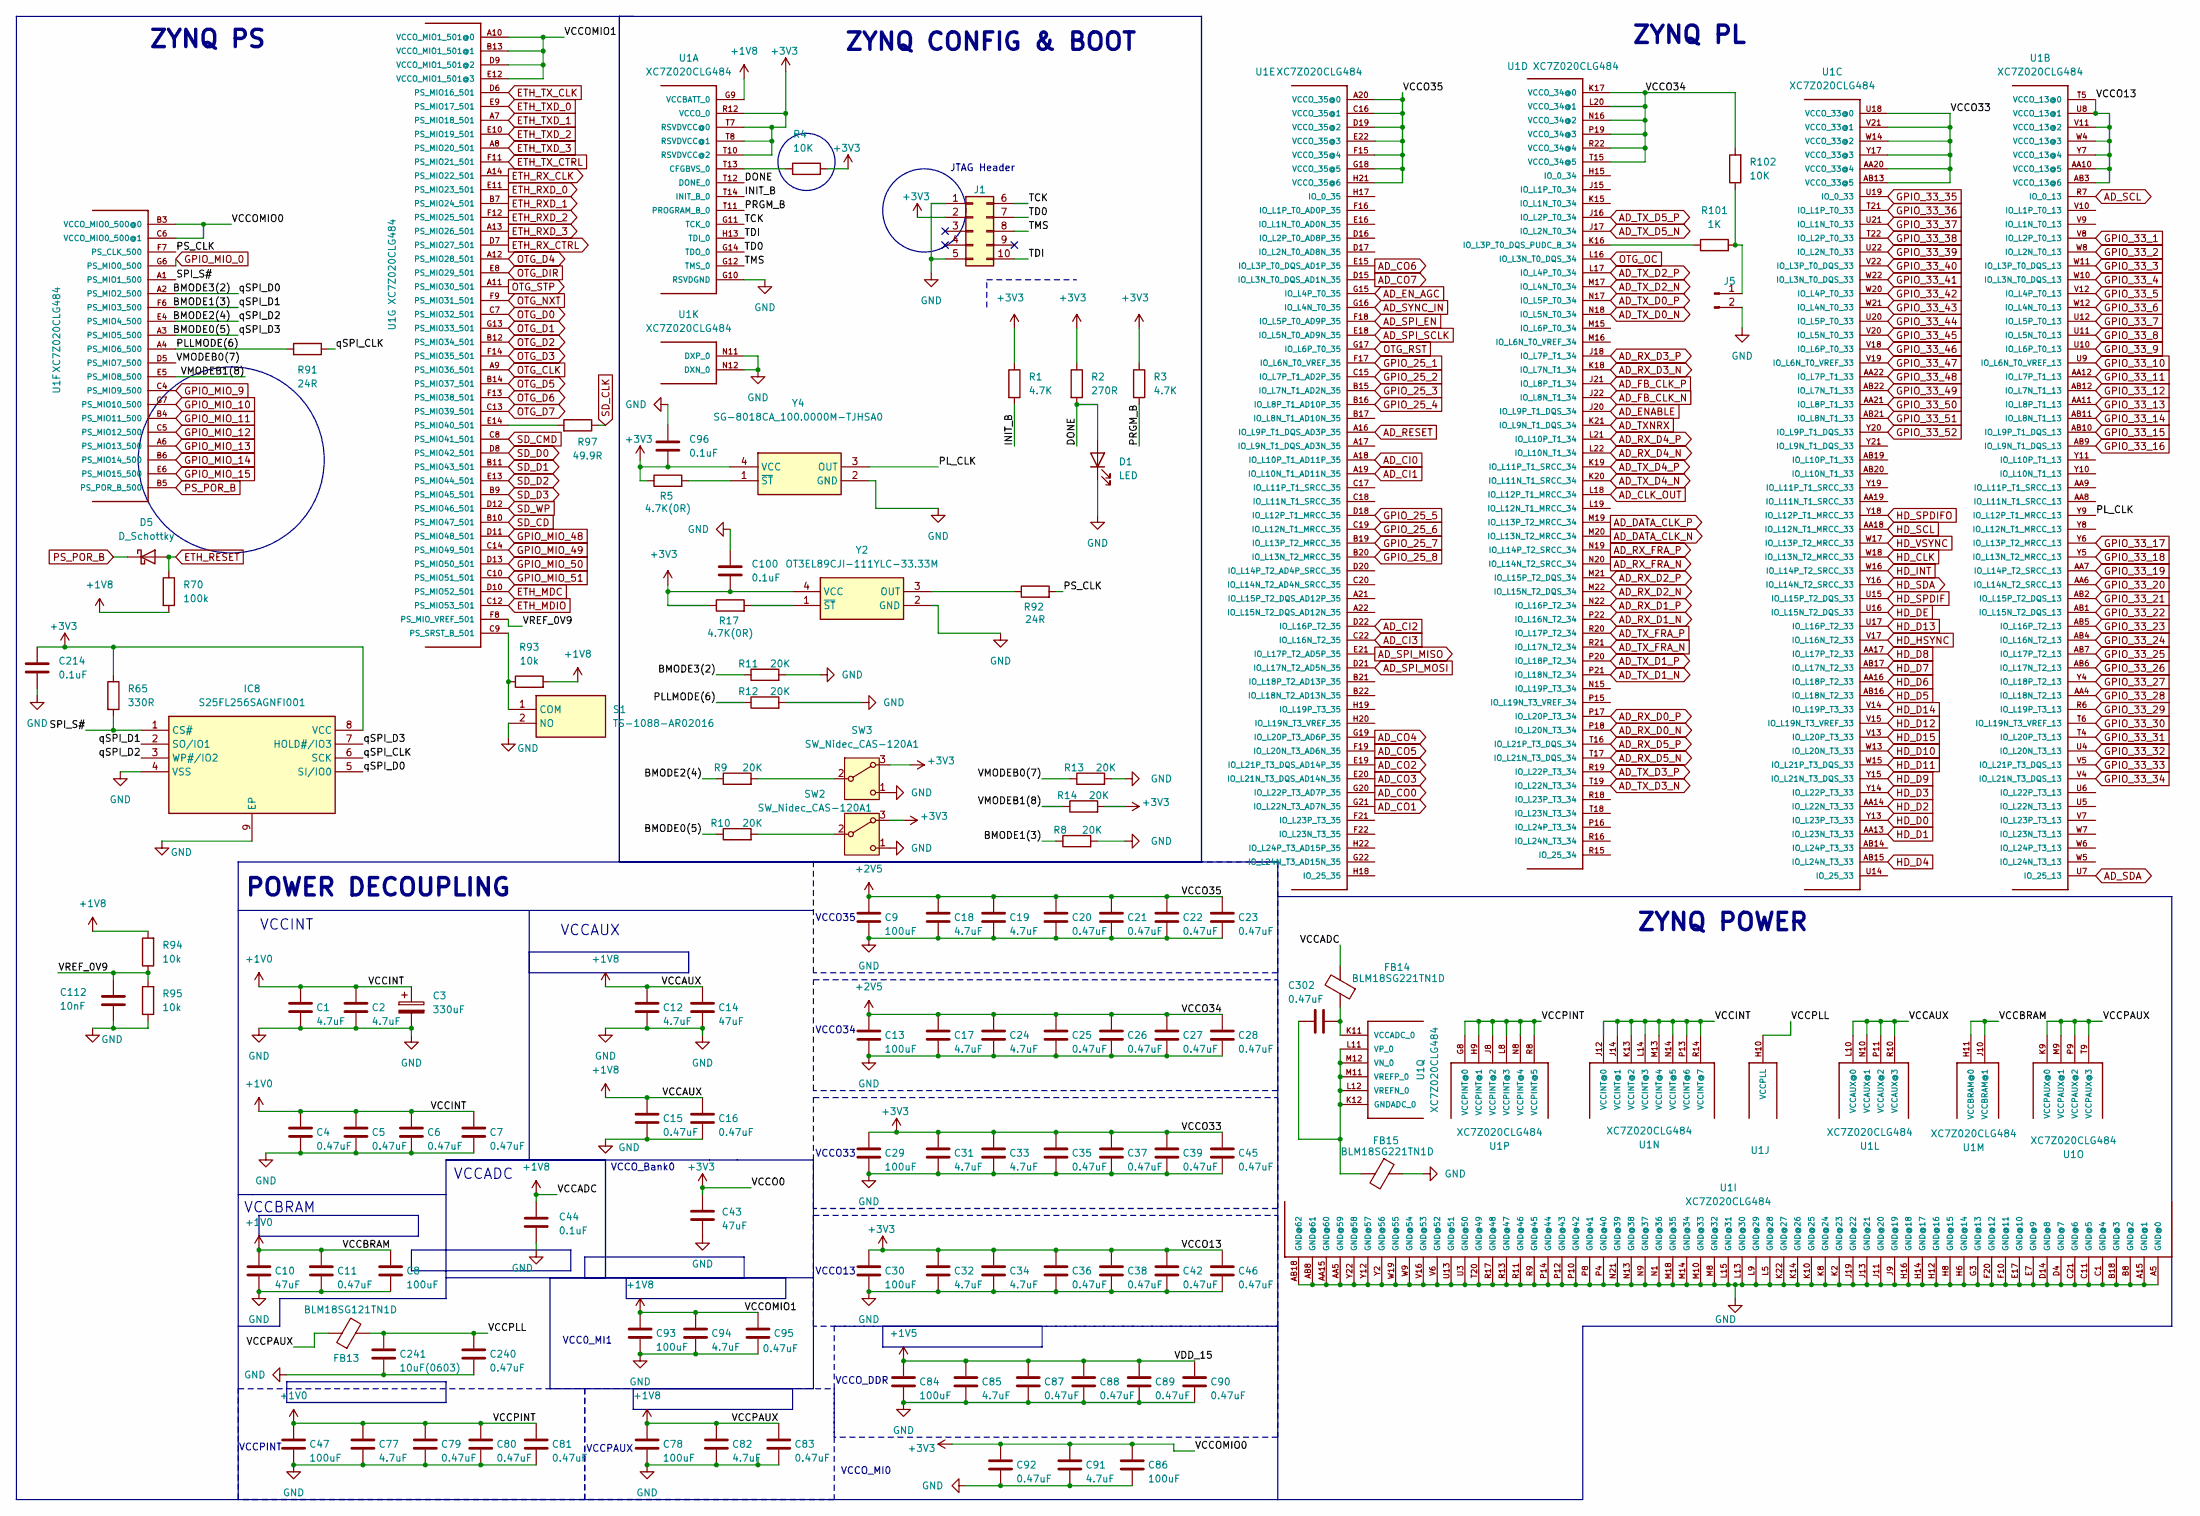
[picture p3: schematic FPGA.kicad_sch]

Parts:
C1, C2: 4.7uF; C_1210_3225Metric
C3: 330uF; CP_EIA-7343-31_Kemet-D
C4, C5, C6, C7, C11, C15, C16, C20, C21, C22, C23, C25, C26, C27, C28, C35, C36, C37, C38, C39, C42, C45, C46, C79, C80, C81, C83, C87, C88, C89, C90, C92, C95, C240, C302: 0.47uF; C_0402_1005Metric
C8, C9, C13, C29, C30, C47, C78, C84, C86, C93: 100uF; C_1210_3225Metric
C10, C14, C43: 47uF; C_1210_3225Metric
C12, C17, C18, C19, C24, C31, C32, C33, C34, C77, C82, C85, C91, C94: 4.7uF; C_0603_1608Metric
C44, C96, C100, C214: 0.1uF; C_0402_1005Metric
C112: 10nF; C_0201_0603Metric
C241: 10uF(0603); C_0603_1608Metric
D1: LED; LED_0805_2012Metric
D5: D_Schottky; D_0805_2012Metric
FB13: BLM18SG121TN1D; L_0603_1608Metric
FB14, FB15: BLM18SG221TN1D; L_0603_1608Metric
IC8: S25FL256SAGNFI001; SON127P800X600X80-9N-D; Manufacturer_Part_Number S25FL256SAGNFI001; Mouser Part Number 797-25FL256SAGNFI001
J1: Conn_02x05_Top_Bottom; PinHeader_2x05_P2.54mm_Horizontal
J5: Conn_01x02_Pin; PinHeader_1x02_P2.54mm_Vertical
R1, R3: 4.7K; R_0402_1005Metric
R2: 270R; R_0402_1005Metric
R4, R102: 10K; R_0402_1005Metric
R5, R17: 4.7K(0R); R_0402_1005Metric
R8, R9, R10, R11, R12, R13, R14: 20K; R_0402_1005Metric
R65: 330R; R_0402_1005Metric
R70: 100k; R_0402_1005Metric
R91, R92: 24R; R_0402_1005Metric
R93, R94, R95: 10k; R_0402_1005Metric
R97: 49.9R; R_0402_1005Metric
R101: 1K; R_0402_1005Metric
S1: TS-1088-AR02016; TS1088AR02016; Manufacturer_Part_Number TS-1088-AR02016
SW2, SW3: SW_Nidec_CAS-120A1; Nidec_Copal_CAS-120A
U1: XC7Z020CLG484; CS484
Y2: OT3EL89CJI-111YLC-33.33M; SG8018CA1000000MTJHSA0; Manufacturer_Part_Number SG-8018CA 100.0000M-TJHSA0
Y4: SG-8018CA_100.0000M-TJHSA0; SG8018CA1000000MTJHSA0; Manufacturer_Part_Number SG-8018CA 100.0000M-TJHSA0

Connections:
+1V0: C1.1, C2.1, C3.1, C4.1, C5.1, C6.1, C7.1, C8.1, C10.1, C11.1, C47.1, C77.1, C79.1, C80.1, C81.1, U1.G8 (VCCPINT@0), U1.H9 (VCCPINT@1), U1.H11 (VCCBRAM@0), U1.J8 (VCCPINT@2), U1.J10 (VCCBRAM@1), U1.J12 (VCCINT@0), U1.J14 (VCCINT@1), U1.K13 (VCCINT@2), U1.L8 (VCCPINT@3), U1.L14 (VCCINT@3), U1.M13 (VCCINT@4), U1.N8 (VCCPINT@4), U1.N14 (VCCINT@5), U1.P13 (VCCINT@6), U1.R8 (VCCPINT@5), U1.R14 (VCCINT@7); also elsewhere on the board
+1V5: C84.1, C85.1, C87.1, C88.1, C89.1, C90.1; also elsewhere on the board
+1V8: C12.1, C14.1, C15.1, C16.1, C44.1, C78.1, C82.1, C83.1, C93.1, C94.1, C95.1, FB13.1, FB14.2, R70.2, R93.2, R94.2, U1.A10 (VCCO_MIO1_501@0), U1.B13 (VCCO_MIO1_501@1), U1.D9 (VCCO_MIO1_501@2), U1.E12 (VCCO_MIO1_501@3), U1.G9 (VCCBATT_0), U1.K9 (VCCPAUX@0), U1.L10 (VCCAUX@0), U1.M9 (VCCPAUX@1), U1.N10 (VCCAUX@1), U1.P9 (VCCPAUX@2), U1.P11 (VCCAUX@2), U1.R10 (VCCAUX@3), U1.T9 (VCCPAUX@3); also elsewhere on the board
/FPGA/BMODE0(5): IC8.7 (HOLD#/IO3), R10.1, U1.A3 (PS_MIO5_500)
/FPGA/BMODE1(3): IC8.2 (SO/IO1), R8.1, U1.F6 (PS_MIO3_500)
/FPGA/BMODE2(4): IC8.3 (WP#/IO2), R9.1, U1.E4 (PS_MIO4_500)
/FPGA/BMODE3(2): IC8.5 (SI/IO0), R11.1, U1.A2 (PS_MIO2_500)
/FPGA/DONE: D1.2 (A), R2.2, U1.T12 (DONE_0)
/FPGA/INIT_B: R1.2, U1.T14 (INIT_B_0)
/FPGA/PLLMODE(6): R12.1, R91.2, U1.A4 (PS_MIO6_500)
/FPGA/PL_CLK: U1.Y9 (IO_L12P_T1_MRCC_13), Y4.3 (OUT)
/FPGA/PRGM_B: R3.2, U1.T11 (PROGRAM_B_0)
/FPGA/PS_CLK: R92.2, U1.F7 (PS_CLK_500)
/FPGA/SPI_S#: IC8.1 (CS#), R65.2, U1.A1 (PS_MIO1_500)
/FPGA/TCK: J1.6, U1.G11 (TCK_0)
/FPGA/TD0: J1.7, U1.G14 (TDO_0)
/FPGA/TDI: J1.10, U1.H13 (TDI_0)
/FPGA/TMS: J1.8, U1.G12 (TMS_0)
/FPGA/VCCPLL: C240.1, C241.1, FB13.2, U1.H10 (VCCPLL)
/FPGA/VMODEB0(7): R13.1, U1.D5 (PS_MIO7_500)
/FPGA/VMODEB1(8): R14.1, U1.E5 (PS_MIO8_500)
/FPGA/VREF_0V9: C112.2, R94.1, R95.2, U1.F8 (PS_MIO_VREF_501)
/FPGA/qSPI_CLK: IC8.6 (SCK), R91.1
AD_CI0: U1.A18 (IO_L10P_T1_AD11P_35); also elsewhere on the board
AD_CI1: U1.A19 (IO_L10N_T1_AD11N_35); also elsewhere on the board
AD_CI2: U1.D22 (IO_L16P_T2_35); also elsewhere on the board
AD_CI3: U1.C22 (IO_L16N_T2_35); also elsewhere on the board
AD_CLK_OUT: U1.L18 (IO_L12P_T1_MRCC_34); also elsewhere on the board
AD_CO0: U1.G20 (IO_L22P_T3_AD7P_35); also elsewhere on the board
AD_CO1: U1.G21 (IO_L22N_T3_AD7N_35); also elsewhere on the board
AD_CO2: U1.E19 (IO_L21P_T3_DQS_AD14P_35); also elsewhere on the board
AD_CO3: U1.E20 (IO_L21N_T3_DQS_AD14N_35); also elsewhere on the board
AD_CO4: U1.G19 (IO_L20P_T3_AD6P_35); also elsewhere on the board
AD_CO5: U1.F19 (IO_L20N_T3_AD6N_35); also elsewhere on the board
AD_CO6: U1.E15 (IO_L3P_T0_DQS_AD1P_35); also elsewhere on the board
AD_CO7: U1.D15 (IO_L3N_T0_DQS_AD1N_35); also elsewhere on the board
AD_DATA_CLK_N: U1.M20 (IO_L13N_T2_MRCC_34); also elsewhere on the board
AD_DATA_CLK_P: U1.M19 (IO_L13P_T2_MRCC_34); also elsewhere on the board
AD_ENABLE: U1.J20 (IO_L9P_T1_DQS_34); also elsewhere on the board
AD_EN_AGC: U1.G15 (IO_L4P_T0_35); also elsewhere on the board
AD_FB_CLK_N: U1.J22 (IO_L8N_T1_34); also elsewhere on the board
AD_FB_CLK_P: U1.J21 (IO_L8P_T1_34); also elsewhere on the board
AD_RESET: U1.A16 (IO_L9P_T1_DQS_AD3P_35); also elsewhere on the board
AD_RX_D0_N: U1.P18 (IO_L20N_T3_34); also elsewhere on the board
AD_RX_D0_P: U1.P17 (IO_L20P_T3_34); also elsewhere on the board
AD_RX_D1_N: U1.P22 (IO_L16N_T2_34); also elsewhere on the board
AD_RX_D1_P: U1.N22 (IO_L16P_T2_34); also elsewhere on the board
AD_RX_D2_N: U1.M22 (IO_L15N_T2_DQS_34); also elsewhere on the board
AD_RX_D2_P: U1.M21 (IO_L15P_T2_DQS_34); also elsewhere on the board
AD_RX_D3_N: U1.K18 (IO_L7N_T1_34); also elsewhere on the board
AD_RX_D3_P: U1.J18 (IO_L7P_T1_34); also elsewhere on the board
AD_RX_D4_N: U1.L22 (IO_L10N_T1_34); also elsewhere on the board
AD_RX_D4_P: U1.L21 (IO_L10P_T1_34); also elsewhere on the board
AD_RX_D5_N: U1.T17 (IO_L21N_T3_DQS_34); also elsewhere on the board
AD_RX_D5_P: U1.T16 (IO_L21P_T3_DQS_34); also elsewhere on the board
AD_RX_FRA_N: U1.N20 (IO_L14N_T2_SRCC_34); also elsewhere on the board
AD_RX_FRA_P: U1.N19 (IO_L14P_T2_SRCC_34); also elsewhere on the board
AD_SCL: U1.R7 (IO_0_13); also elsewhere on the board
AD_SDA: U1.U7 (IO_25_13); also elsewhere on the board
AD_SPI_EN: U1.F18 (IO_L5P_T0_AD9P_35); also elsewhere on the board
AD_SPI_MISO: U1.E21 (IO_L17P_T2_AD5P_35); also elsewhere on the board
AD_SPI_MOSI: U1.D21 (IO_L17N_T2_AD5N_35); also elsewhere on the board
AD_SPI_SCLK: U1.E18 (IO_L5N_T0_AD9N_35); also elsewhere on the board
AD_SYNC_IN: U1.G16 (IO_L4N_T0_35); also elsewhere on the board
AD_TXNRX: U1.K21 (IO_L9N_T1_DQS_34); also elsewhere on the board
AD_TX_D0_N: U1.N18 (IO_L5N_T0_34); also elsewhere on the board
AD_TX_D0_P: U1.N17 (IO_L5P_T0_34); also elsewhere on the board
AD_TX_D1_N: U1.P21 (IO_L18N_T2_34); also elsewhere on the board
AD_TX_D1_P: U1.P20 (IO_L18P_T2_34); also elsewhere on the board
AD_TX_D2_N: U1.M17 (IO_L4N_T0_34); also elsewhere on the board
AD_TX_D2_P: U1.L17 (IO_L4P_T0_34); also elsewhere on the board
AD_TX_D3_N: U1.T19 (IO_L22N_T3_34); also elsewhere on the board
AD_TX_D3_P: U1.R19 (IO_L22P_T3_34); also elsewhere on the board
AD_TX_D4_N: U1.K20 (IO_L11N_T1_SRCC_34); also elsewhere on the board
AD_TX_D4_P: U1.K19 (IO_L11P_T1_SRCC_34); also elsewhere on the board
AD_TX_D5_N: U1.J17 (IO_L2N_T0_34); also elsewhere on the board
AD_TX_D5_P: U1.J16 (IO_L2P_T0_34); also elsewhere on the board
AD_TX_FRA_N: U1.R21 (IO_L17N_T2_34); also elsewhere on the board
AD_TX_FRA_P: U1.R20 (IO_L17P_T2_34); also elsewhere on the board
ETH_MDC: U1.D10 (PS_MIO52_501); also elsewhere on the board
ETH_MDIO: U1.C12 (PS_MIO53_501); also elsewhere on the board
ETH_RESET: D5.2 (A), R70.1; also elsewhere on the board
ETH_RXD_0: U1.E11 (PS_MIO23_501); also elsewhere on the board
ETH_RXD_1: U1.B7 (PS_MIO24_501); also elsewhere on the board
ETH_RXD_2: U1.F12 (PS_MIO25_501); also elsewhere on the board
ETH_RXD_3: U1.A13 (PS_MIO26_501); also elsewhere on the board
ETH_RX_CLK: U1.A14 (PS_MIO22_501); also elsewhere on the board
ETH_RX_CTRL: U1.D7 (PS_MIO27_501); also elsewhere on the board
ETH_TXD_0: U1.E9 (PS_MIO17_501); also elsewhere on the board
ETH_TXD_1: U1.A7 (PS_MIO18_501); also elsewhere on the board
ETH_TXD_2: U1.E10 (PS_MIO19_501); also elsewhere on the board
ETH_TXD_3: U1.A8 (PS_MIO20_501); also elsewhere on the board
ETH_TX_CLK: U1.D6 (PS_MIO16_501); also elsewhere on the board
ETH_TX_CTRL: U1.F11 (PS_MIO21_501); also elsewhere on the board
GPIO_25_1: U1.F17 (IO_L6N_T0_VREF_35)
GPIO_25_2: U1.C15 (IO_L7P_T1_AD2P_35)
GPIO_25_3: U1.B15 (IO_L7N_T1_AD2N_35)
GPIO_25_4: U1.B16 (IO_L8P_T1_AD10P_35)
GPIO_25_5: U1.D18 (IO_L12P_T1_MRCC_35)
GPIO_25_6: U1.C19 (IO_L12N_T1_MRCC_35)
GPIO_25_7: U1.B19 (IO_L13P_T2_MRCC_35)
GPIO_25_8: U1.B20 (IO_L13N_T2_MRCC_35)
GPIO_33_1: U1.V8 (IO_L2P_T0_13); also elsewhere on the board
GPIO_33_2: U1.W8 (IO_L2N_T0_13); also elsewhere on the board
GPIO_33_3: U1.W11 (IO_L3P_T0_DQS_13); also elsewhere on the board
GPIO_33_4: U1.W10 (IO_L3N_T0_DQS_13); also elsewhere on the board
GPIO_33_5: U1.V12 (IO_L4P_T0_13); also elsewhere on the board
GPIO_33_6: U1.W12 (IO_L4N_T0_13); also elsewhere on the board
GPIO_33_7: U1.U12 (IO_L5P_T0_13); also elsewhere on the board
GPIO_33_8: U1.U11 (IO_L5N_T0_13); also elsewhere on the board
GPIO_33_9: U1.U10 (IO_L6P_T0_13); also elsewhere on the board
GPIO_33_10: U1.U9 (IO_L6N_T0_VREF_13); also elsewhere on the board
GPIO_33_11: U1.AA12 (IO_L7P_T1_13); also elsewhere on the board
GPIO_33_12: U1.AB12 (IO_L7N_T1_13); also elsewhere on the board
GPIO_33_13: U1.AA11 (IO_L8P_T1_13); also elsewhere on the board
GPIO_33_14: U1.AB11 (IO_L8N_T1_13); also elsewhere on the board
GPIO_33_15: U1.AB10 (IO_L9P_T1_DQS_13); also elsewhere on the board
GPIO_33_16: U1.AB9 (IO_L9N_T1_DQS_13); also elsewhere on the board
GPIO_33_17: U1.Y6 (IO_L13P_T2_MRCC_13); also elsewhere on the board
GPIO_33_18: U1.Y5 (IO_L13N_T2_MRCC_13); also elsewhere on the board
GPIO_33_19: U1.AA7 (IO_L14P_T2_SRCC_13); also elsewhere on the board
GPIO_33_20: U1.AA6 (IO_L14N_T2_SRCC_13); also elsewhere on the board
GPIO_33_21: U1.AB2 (IO_L15P_T2_DQS_13); also elsewhere on the board
GPIO_33_22: U1.AB1 (IO_L15N_T2_DQS_13); also elsewhere on the board
GPIO_33_23: U1.AB5 (IO_L16P_T2_13); also elsewhere on the board
GPIO_33_24: U1.AB4 (IO_L16N_T2_13); also elsewhere on the board
GPIO_33_25: U1.AB7 (IO_L17P_T2_13); also elsewhere on the board
GPIO_33_26: U1.AB6 (IO_L17N_T2_13); also elsewhere on the board
GPIO_33_27: U1.Y4 (IO_L18P_T2_13); also elsewhere on the board
GPIO_33_28: U1.AA4 (IO_L18N_T2_13); also elsewhere on the board
GPIO_33_29: U1.R6 (IO_L19P_T3_13); also elsewhere on the board
GPIO_33_30: U1.T6 (IO_L19N_T3_VREF_13); also elsewhere on the board
GPIO_33_31: U1.T4 (IO_L20P_T3_13); also elsewhere on the board
GPIO_33_32: U1.U4 (IO_L20N_T3_13); also elsewhere on the board
GPIO_33_33: U1.V5 (IO_L21P_T3_DQS_13); also elsewhere on the board
GPIO_33_34: U1.V4 (IO_L21N_T3_DQS_13); also elsewhere on the board
GPIO_33_35: U1.U19 (IO_0_33)
GPIO_33_36: U1.T21 (IO_L1P_T0_33)
GPIO_33_37: U1.U21 (IO_L1N_T0_33)
GPIO_33_38: U1.T22 (IO_L2P_T0_33)
GPIO_33_39: U1.U22 (IO_L2N_T0_33)
GPIO_33_40: U1.V22 (IO_L3P_T0_DQS_33)
GPIO_33_41: U1.W22 (IO_L3N_T0_DQS_33)
GPIO_33_42: U1.W20 (IO_L4P_T0_33)
GPIO_33_43: U1.W21 (IO_L4N_T0_33)
GPIO_33_44: U1.U20 (IO_L5P_T0_33)
GPIO_33_45: U1.V20 (IO_L5N_T0_33)
GPIO_33_46: U1.V18 (IO_L6P_T0_33)
GPIO_33_47: U1.V19 (IO_L6N_T0_VREF_33)
GPIO_33_48: U1.AA22 (IO_L7P_T1_33)
GPIO_33_49: U1.AB22 (IO_L7N_T1_33)
GPIO_33_50: U1.AA21 (IO_L8P_T1_33)
GPIO_33_51: U1.AB21 (IO_L8N_T1_33)
GPIO_33_52: U1.Y20 (IO_L9P_T1_DQS_33)
GPIO_MIO_0: U1.G6 (PS_MIO0_500)
GPIO_MIO_9: U1.C4 (PS_MIO9_500)
GPIO_MIO_10: U1.G7 (PS_MIO10_500)
GPIO_MIO_11: U1.B4 (PS_MIO11_500)
GPIO_MIO_12: U1.C5 (PS_MIO12_500)
GPIO_MIO_13: U1.A6 (PS_MIO13_500)
GPIO_MIO_14: U1.B6 (PS_MIO14_500)
GPIO_MIO_15: U1.E6 (PS_MIO15_500)
GPIO_MIO_48: U1.D11 (PS_MIO48_501)
GPIO_MIO_49: U1.C14 (PS_MIO49_501)
GPIO_MIO_50: U1.D13 (PS_MIO50_501)
GPIO_MIO_51: U1.C10 (PS_MIO51_501)
HD_CLK: U1.W18 (IO_L13N_T2_MRCC_33); also elsewhere on the board
HD_D0: U1.Y13 (IO_L23P_T3_33); also elsewhere on the board
HD_D1: U1.AA13 (IO_L23N_T3_33); also elsewhere on the board
HD_D2: U1.AA14 (IO_L22N_T3_33); also elsewhere on the board
HD_D3: U1.Y14 (IO_L22P_T3_33); also elsewhere on the board
HD_D4: U1.AB15 (IO_L24N_T3_33); also elsewhere on the board
HD_D5: U1.AB16 (IO_L18N_T2_33); also elsewhere on the board
HD_D6: U1.AA16 (IO_L18P_T2_33); also elsewhere on the board
HD_D7: U1.AB17 (IO_L17N_T2_33); also elsewhere on the board
HD_D8: U1.AA17 (IO_L17P_T2_33); also elsewhere on the board
HD_D9: U1.Y15 (IO_L21N_T3_DQS_33); also elsewhere on the board
HD_D10: U1.W13 (IO_L20N_T3_33); also elsewhere on the board
HD_D11: U1.W15 (IO_L21P_T3_DQS_33); also elsewhere on the board
HD_D12: U1.V15 (IO_L19N_T3_VREF_33); also elsewhere on the board
HD_D13: U1.U17 (IO_L16P_T2_33); also elsewhere on the board
HD_D14: U1.V14 (IO_L19P_T3_33); also elsewhere on the board
HD_D15: U1.V13 (IO_L20P_T3_33); also elsewhere on the board
HD_DE: U1.U16 (IO_L15N_T2_DQS_33); also elsewhere on the board
HD_HSYNC: U1.V17 (IO_L16N_T2_33); also elsewhere on the board
HD_INT: U1.W16 (IO_L14P_T2_SRCC_33); also elsewhere on the board
HD_SCL: U1.AA18 (IO_L12N_T1_MRCC_33); also elsewhere on the board
HD_SDA: U1.Y16 (IO_L14N_T2_SRCC_33); also elsewhere on the board
HD_SPDIF: U1.U15 (IO_L15P_T2_DQS_33); also elsewhere on the board
HD_SPDIFO: U1.Y18 (IO_L12P_T1_MRCC_33); also elsewhere on the board
HD_VSYNC: U1.W17 (IO_L13P_T2_MRCC_33); also elsewhere on the board
unnamed: J5.1, R101.2, R102.1
unnamed: R93.1, S1.1 (COM), U1.C9 (PS_SRST_B_501)
unnamed: R10.2, SW2.2 (B)
unnamed: R9.2, SW3.2 (B)
unnamed: R4.1, U1.T13 (CFGBVS_0)
unnamed: R101.1, U1.K16 (IO_L3P_T0_DQS_PUDC_B_34)
unnamed: R97.2, U1.E14 (PS_MIO40_501)
unnamed: C302.1, FB15.2, U1.K12 (GNDADC_0), U1.L11 (VP_0), U1.L12 (VREFN_0), U1.M11 (VREFP_0), U1.M12 (VN_0)
unnamed: C302.2, FB14.1, U1.K11 (VCCADC_0)
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

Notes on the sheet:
VCCO35
VCCO13
VCCINT
VCCO_Bank0
ZYNQ PS
VCCBRAM
JTAG Header
VCCO34
VCC0_MI1
ZYNQ POWER
VCCPAUX
ZYNQ PL
POWER DECOUPLING
VCCO33
VCCO_MI0
VCCPINT
ZYNQ CONFIG & BOOT
VCCO_DDR
VCCADC
VCCAUX

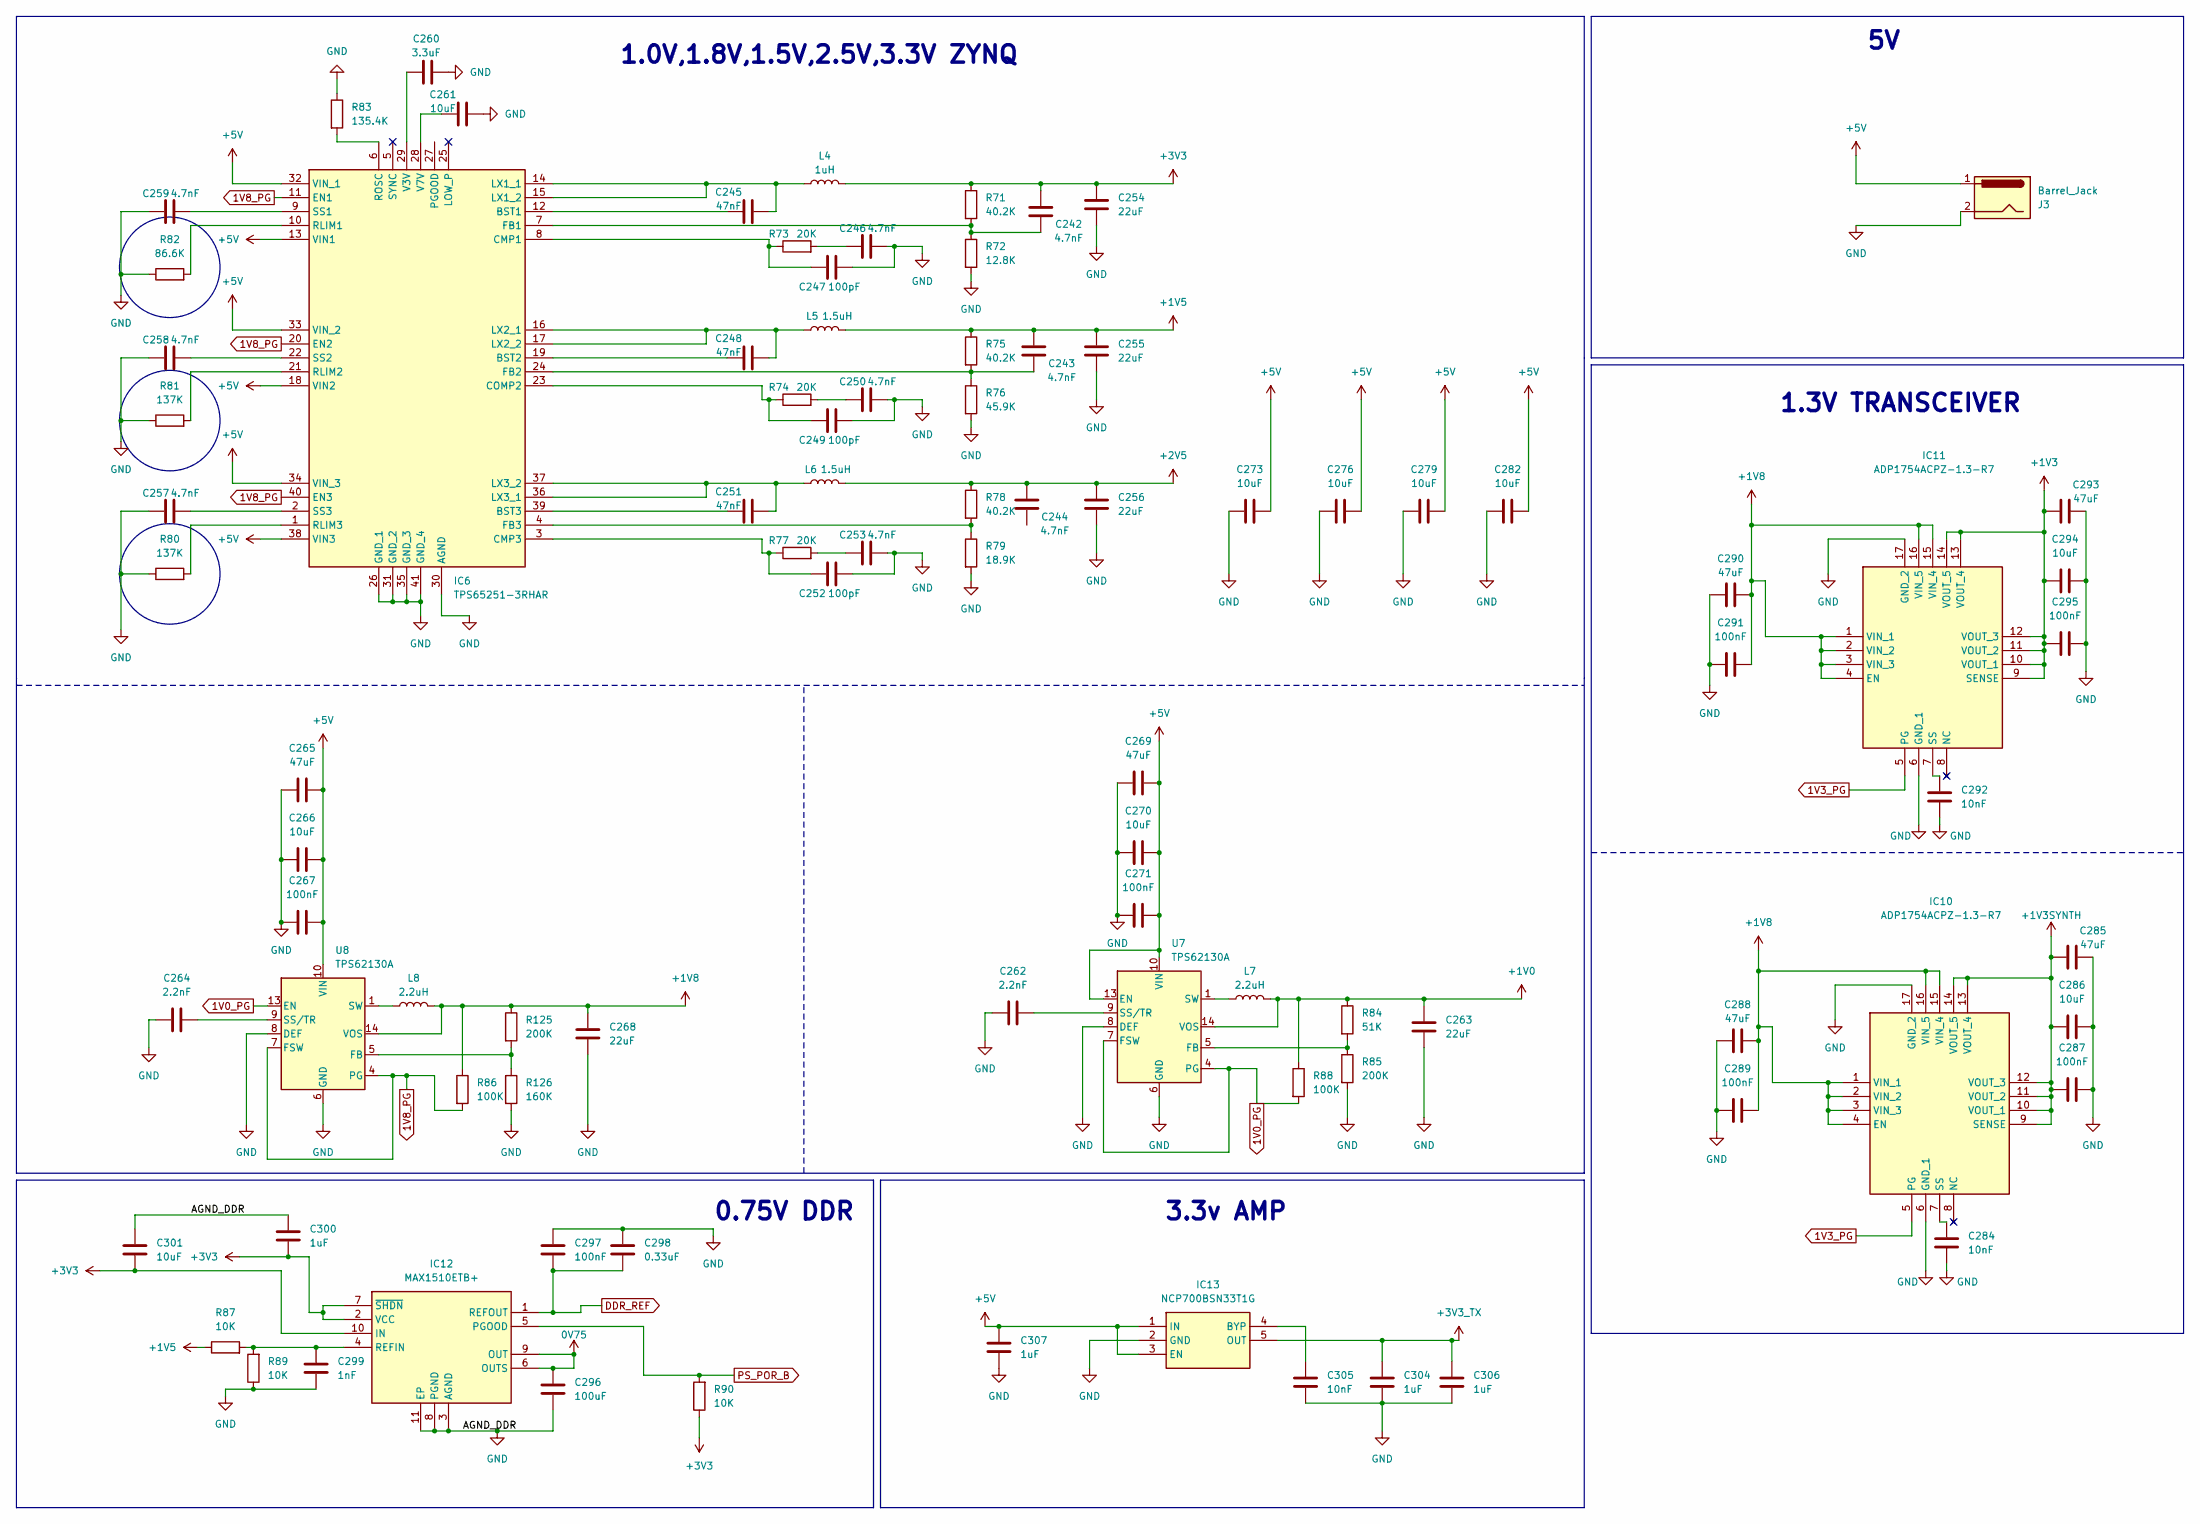
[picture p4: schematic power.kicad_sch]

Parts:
C242, C243, C244, C246, C250, C253, C257, C258, C259: 4.7nF; C_0201_0603Metric
C245, C248, C251: 47nF; C_0201_0603Metric
C247, C249, C252: 100pF; C_0201_0603Metric
C254, C255, C256: 22uF; C_1210_3225Metric
C260: 3.3uF; C_0603_1608Metric
C261, C266, C270, C273, C276, C279, C282, C286, C294, C301: 10uF; C_0603_1608Metric
C262, C264: 2.2nF; C_0201_0603Metric
C263, C268: 22uF; C_0805_2012Metric
C265, C269, C288: 47uF; C_0805_2012Metric
C267, C271, C287, C289, C291, C295, C297: 100nF; C_0402_1005Metric
C284, C292, C305: 10nF; C_0201_0603Metric
C285, C290, C293: 47uF; C_1206_3216Metric
C296: 100uF; C_0402_1005Metric
C298: 0.33uF; C_0402_1005Metric
C299: 1nF; C_0201_0603Metric
C300, C304, C306, C307: 1uF; C_0603_1608Metric
IC6: TPS65251-3RHAR; QFN50P600X600X100-41N-D; Manufacturer_Part_Number TPS65251-3RHAR; Mouser Part Number 595-TPS65251-3RHAR
IC10, IC11: ADP1754ACPZ-1.3-R7; QFN65P400X400X80-17N-D; Manufacturer_Part_Number ADP1754ACPZ-1.3-R7; Mouser Part Number 584-P1754ACPZ13R7
IC12: MAX1510ETB+; SON50P300X300X80-11N; Manufacturer_Part_Number MAX1510ETB+; Mouser Part Number N/A
IC13: NCP700BSN33T1G; SOT95P275X110-5N; Manufacturer_Part_Number NCP700BSN33T1G; Mouser Part Number 863-NCP700BSN33T1G
J3: Barrel_Jack; BarrelJack_SwitchcraftConxall_RAPC10U_Horizontal
L4: 1uH; XFL4020-222ME
L5, L6: 1.5uH; XFL4020-222ME
L7, L8: 2.2uH; XFL4020-222ME
R71, R75, R78: 40.2K; R_0402_1005Metric
R72: 12.8K; R_0402_1005Metric
R73, R74, R77: 20K; R_0402_1005Metric
R76: 45.9K; R_0402_1005Metric
R79: 18.9K; R_0402_1005Metric
R80, R81: 137K; R_0402_1005Metric
R82: 86.6K; R_0402_1005Metric
R83: 135.4K; R_0402_1005Metric
R84: 51K; R_0402_1005Metric
R85, R125: 200K; R_0402_1005Metric
R86, R88: 100K; R_0402_1005Metric
R87, R89, R90: 10K; R_0402_1005Metric
R126: 160K; R_0402_1005Metric
U7, U8: TPS62130A; VQFN-16-1EP_3x3mm_P0.5mm_EP1.68x1.68mm_ThermalVias

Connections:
0V75: C296.1, IC12.6 (OUTS), IC12.9 (OUT); also elsewhere on the board
1V0_PG: R88.2, U7.4 (PG), U7.7 (FSW), U8.13 (EN)
1V3_PG: IC10.5 (PG), IC11.5 (PG)
1V8_PG: IC6.11 (EN1), IC6.20 (EN2), IC6.40 (EN3), R86.2, U8.4 (PG), U8.7 (FSW)
+1V0: C263.1, L7.2, R84.1, R88.1, U7.14 (VOS); also elsewhere on the board
+1V3: C293.1, C294.1, C295.1, IC11.9 (SENSE), IC11.10 (VOUT_1), IC11.11 (VOUT_2), IC11.12 (VOUT_3), IC11.13 (VOUT_4), IC11.14 (VOUT_5); also elsewhere on the board
+1V3SYNTH: C285.1, C286.1, C287.1, IC10.9 (SENSE), IC10.10 (VOUT_1), IC10.11 (VOUT_2), IC10.12 (VOUT_3), IC10.13 (VOUT_4), IC10.14 (VOUT_5); also elsewhere on the board
+1V5: C243.2, C255.1, L5.2, R75.1, R87.1; also elsewhere on the board
+1V8: C268.1, C288.2, C289.2, C290.2, C291.2, IC10.1 (VIN_1), IC10.2 (VIN_2), IC10.3 (VIN_3), IC10.4 (EN), IC10.15 (VIN_4), IC10.16 (VIN_5), IC11.1 (VIN_1), IC11.2 (VIN_2), IC11.3 (VIN_3), IC11.4 (EN), IC11.15 (VIN_4), IC11.16 (VIN_5), L8.2, R86.1, R125.1, U8.14 (VOS); also elsewhere on the board
+5V: C265.2, C266.2, C267.2, C269.2, C270.2, C271.2, C273.2, C276.2, C279.2, C282.2, C307.1, IC6.13 (VIN1), IC6.18 (VIN2), IC6.32 (VIN_1), IC6.33 (VIN_2), IC6.34 (VIN_3), IC6.38 (VIN3), IC13.1 (IN), IC13.3 (EN), J3.1, U7.10 (VIN), U7.11 (VIN), U7.12 (VIN), U7.13 (EN), U8.10 (VIN), U8.11 (VIN), U8.12 (VIN); also elsewhere on the board
DDR_REF: C297.2, C298.2, IC12.1 (REFOUT); also elsewhere on the board
unnamed: C246.1, R73.2
unnamed: C250.1, R74.2
unnamed: C253.1, R77.2
unnamed: C245.1, IC6.12 (BST1)
unnamed: C248.1, IC6.19 (BST2)
unnamed: C251.1, IC6.39 (BST3)
unnamed: C247.1, IC6.8 (CMP1), R73.1
unnamed: C252.1, IC6.3 (CMP3), R77.1
unnamed: C249.1, IC6.23 (COMP2), R74.1
unnamed: C243.1, IC6.24 (FB2), R75.2, R76.1
unnamed: IC6.4 (FB3), R78.2, R79.1
unnamed: C245.2, IC6.14 (LX1_1), IC6.15 (LX1_2), L4.1
unnamed: C248.2, IC6.16 (LX2_1), IC6.17 (LX2_2), L5.1
unnamed: C251.2, IC6.36 (LX3_1), IC6.37 (LX3_2), L6.1
unnamed: IC6.10 (RLIM1), R82.2
unnamed: IC6.21 (RLIM2), R81.2
unnamed: IC6.1 (RLIM3), R80.2
unnamed: IC6.6 (ROSC), R83.2
unnamed: C259.2, IC6.9 (SS1)
unnamed: C258.2, IC6.22 (SS2)
unnamed: C257.2, IC6.2 (SS3)
unnamed: C260.1, IC6.29 (V3V)
unnamed: C261.1, IC6.28 (V7V)
unnamed: C284.2, IC10.7 (SS)
unnamed: C292.2, IC11.7 (SS)
unnamed: C299.1, IC12.4 (REFIN), R87.2, R89.2
unnamed: C305.1, IC13.4 (BYP)
unnamed: L7.1, U7.1 (SW), U7.2 (SW), U7.3 (SW)
unnamed: L8.1, U8.1 (SW), U8.2 (SW), U8.3 (SW)
unnamed: R84.2, R85.1, U7.5 (FB)
unnamed: C262.2, U7.9 (SS/TR)
unnamed: R125.2, R126.1, U8.5 (FB)
unnamed: C264.2, U8.9 (SS/TR)
PS_POR_B: IC12.5 (PGOOD), R90.2; also elsewhere on the board

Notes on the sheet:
1.3V TRANSCEIVER
0.75V DDR
1.0V,1.8V,1.5V,2.5V,3.3V ZYNQ
3.3v AMP

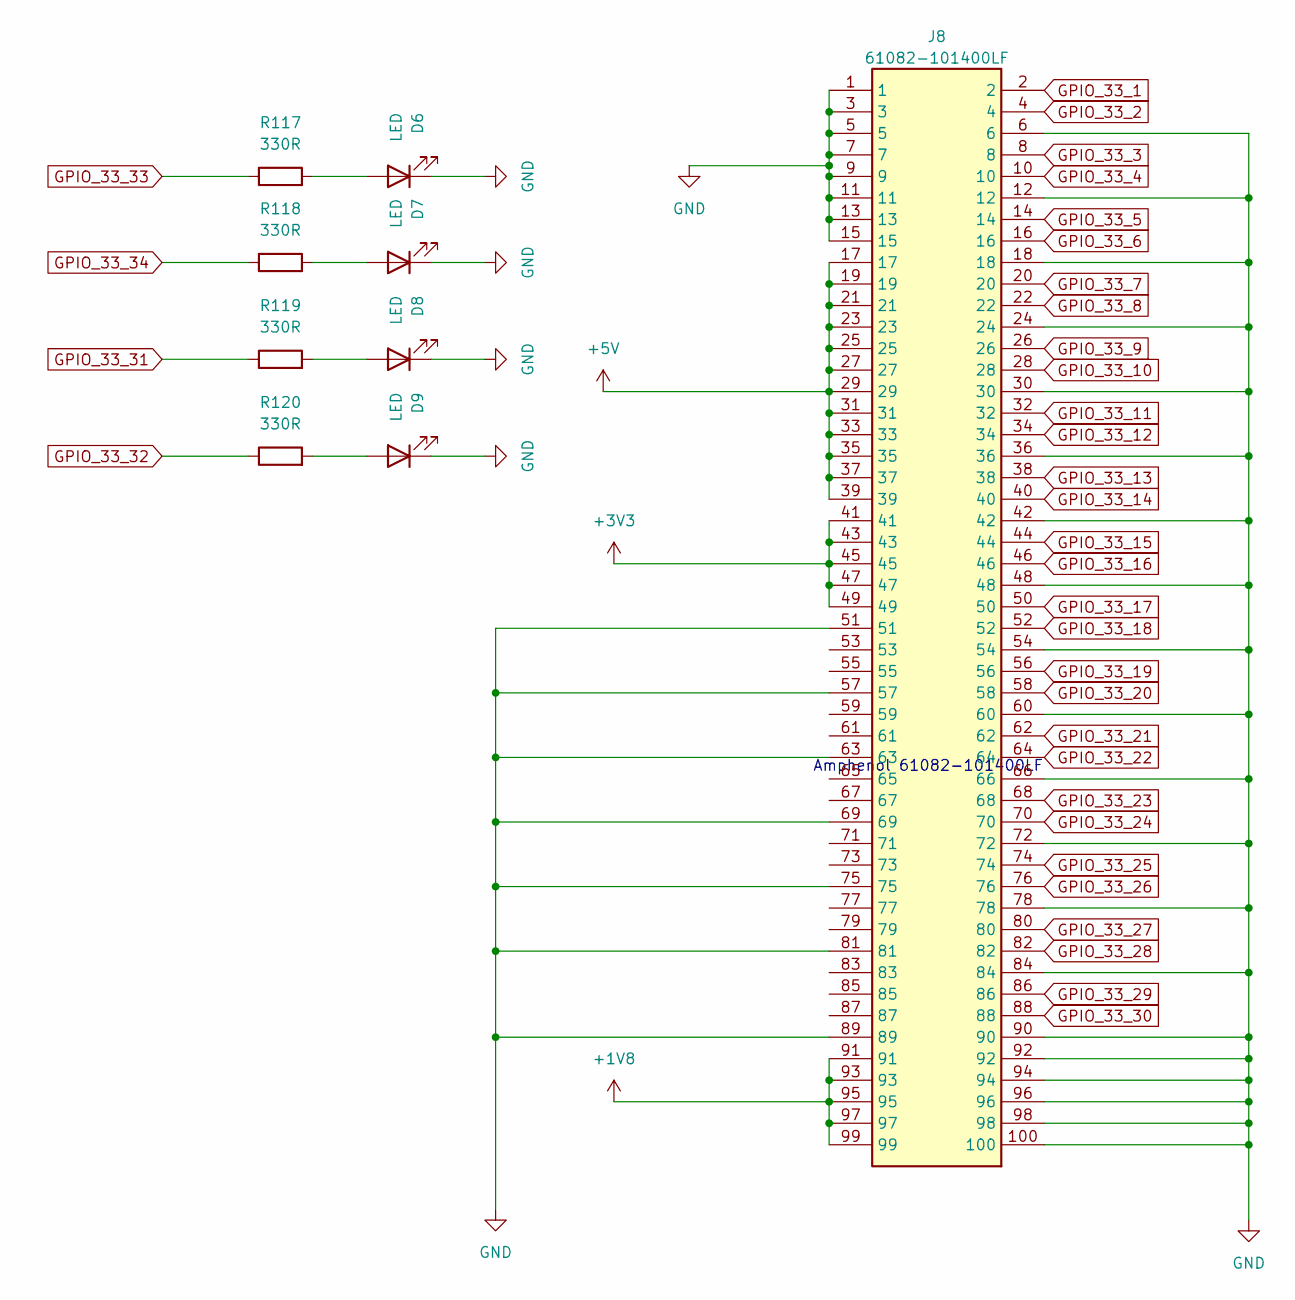
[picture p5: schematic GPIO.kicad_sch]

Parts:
D6, D7, D8, D9: LED; LED_0805_2012Metric
J8: 61082-101400LF; 61082101400LF; Manufacturer_Part_Number 61082-101400LF
R117, R118, R119, R120: 330R; R_0402_1005Metric

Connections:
+1V8: J8.91, J8.93, J8.95, J8.97, J8.99; also elsewhere on the board
+5V: J8.17, J8.19, J8.21, J8.23, J8.25, J8.27, J8.29, J8.31, J8.33, J8.35, J8.37, J8.39; also elsewhere on the board
GPIO_33_1: J8.2; also elsewhere on the board
GPIO_33_2: J8.4; also elsewhere on the board
GPIO_33_3: J8.8; also elsewhere on the board
GPIO_33_4: J8.10; also elsewhere on the board
GPIO_33_5: J8.14; also elsewhere on the board
GPIO_33_6: J8.16; also elsewhere on the board
GPIO_33_7: J8.20; also elsewhere on the board
GPIO_33_8: J8.22; also elsewhere on the board
GPIO_33_9: J8.26; also elsewhere on the board
GPIO_33_10: J8.28; also elsewhere on the board
GPIO_33_11: J8.32; also elsewhere on the board
GPIO_33_12: J8.34; also elsewhere on the board
GPIO_33_13: J8.38; also elsewhere on the board
GPIO_33_14: J8.40; also elsewhere on the board
GPIO_33_15: J8.44; also elsewhere on the board
GPIO_33_16: J8.46; also elsewhere on the board
GPIO_33_17: J8.50; also elsewhere on the board
GPIO_33_18: J8.52; also elsewhere on the board
GPIO_33_19: J8.56; also elsewhere on the board
GPIO_33_20: J8.58; also elsewhere on the board
GPIO_33_21: J8.62; also elsewhere on the board
GPIO_33_22: J8.64; also elsewhere on the board
GPIO_33_23: J8.68; also elsewhere on the board
GPIO_33_24: J8.70; also elsewhere on the board
GPIO_33_25: J8.74; also elsewhere on the board
GPIO_33_26: J8.76; also elsewhere on the board
GPIO_33_27: J8.80; also elsewhere on the board
GPIO_33_28: J8.82; also elsewhere on the board
GPIO_33_29: J8.86; also elsewhere on the board
GPIO_33_30: J8.88; also elsewhere on the board
GPIO_33_31: R119.1; also elsewhere on the board
GPIO_33_32: R120.1; also elsewhere on the board
GPIO_33_33: R117.1; also elsewhere on the board
GPIO_33_34: R118.1; also elsewhere on the board
unnamed: D6.2 (A), R117.2
unnamed: D7.2 (A), R118.2
unnamed: D8.2 (A), R119.2
unnamed: D9.2 (A), R120.2

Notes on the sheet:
Amphenol 61082-101400LF

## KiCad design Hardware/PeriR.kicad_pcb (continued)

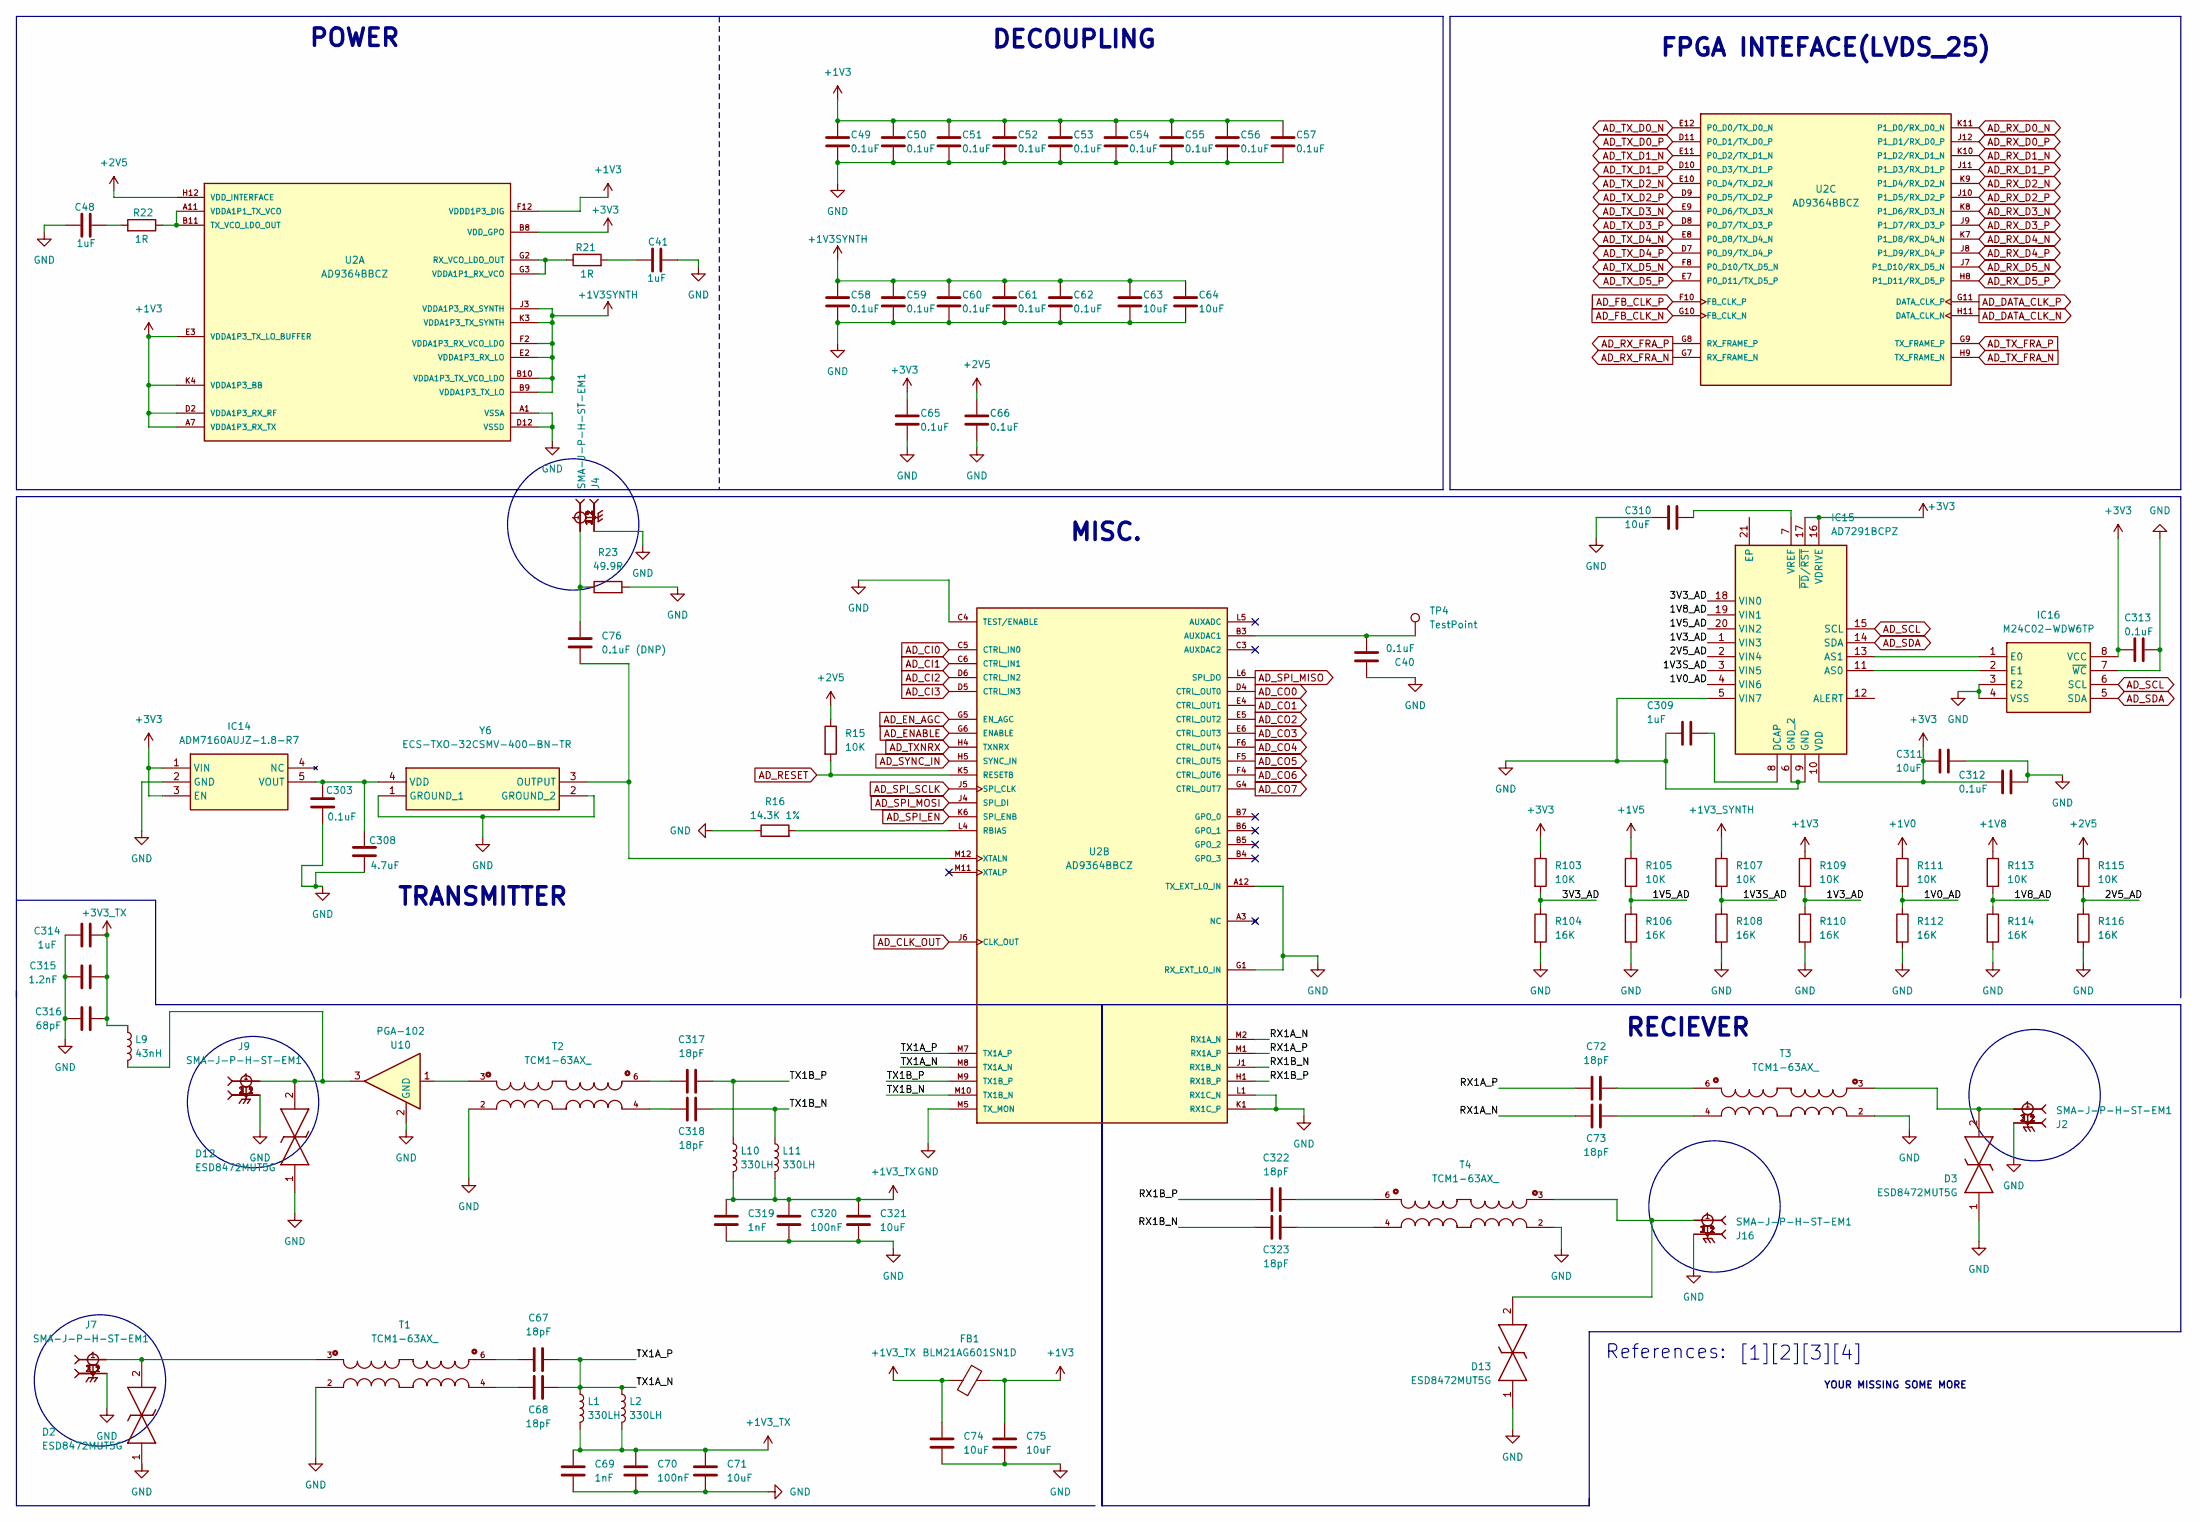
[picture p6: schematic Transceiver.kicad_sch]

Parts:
C40, C49, C50, C51, C52, C53, C54, C55, C56, C57, C58, C59, C60, C61, C62, C65, C66, C303, C312, C313: 0.1uF; C_0402_1005Metric
C41, C48, C309, C314: 1uF; C_0603_1608Metric
C63, C64, C71, C74, C75, C310, C311: 10uF; C_0603_1608Metric
C67, C68, C72, C73, C317, C318, C322, C323: 18pF; C_0201_0603Metric
C69, C319: 1nF; C_0201_0603Metric
C70, C320: 100nF; C_0402_1005Metric
C76: 0.1uF (DNP); C_0402_1005Metric
C308: 4.7uF; C_0603_1608Metric
C315: 1.2nF; C_0201_0603Metric
C316: 68pF; C_0201_0603Metric
C321: 10uF; C_0201_0603Metric
D2, D3, D12, D13: ESD8472MUT5G; X3DFN2-CASE152AF-ISSUE-A; Mouser Part Number 863-ESD8472MUT5G
FB1: BLM21AG601SN1D; L_0603_1608Metric
IC14: ADM7160AUJZ-1.8-R7; SOT95P280X100-5N; Manufacturer_Part_Number ADM7160AUJZ-1.8-R7; Mouser Part Number 584-ADM7160AUJZ1.8R7
IC15: AD7291BCPZ; QFN50P400X400X80-21N; Manufacturer_Part_Number AD7291BCPZ; Mouser Part Number 584-AD7291BCPZ
IC16: M24C02-WDW6TP; SOP65P640X120-8N; Manufacturer_Part_Number M24C02-WDW6TP; Mouser Part Number 511-M24C02-WDW6TP
J2, J4, J7, J9, J16: SMA-J-P-H-ST-EM1; SAMTEC_SMA-J-P-H-ST-EM1; PARTREV G
L1, L2, L10, L11: 330LH; L_0603_1608Metric
L9: 43nH; L_0603_1608Metric
R15, R103, R105, R107, R109, R111, R113, R115: 10K; R_0402_1005Metric
R16: 14.3K 1%; R_0402_1005Metric
R21, R22: 1R; R_0402_1005Metric
R23: 49.9R; R_0402_1005Metric
R104, R106, R108, R110, R112, R114, R116: 16K; R_0402_1005Metric
T1, T2, T3, T4: TCM1-63AX_; TCM163AX
TP4: TestPoint; TestPoint_Pad_1.0x1.0mm
U2: AD9364BBCZ; BGA144C80P12X12_1000X1000X170N; PARTREV C
U10: PGA-102; SOT-89-3
Y6: ECS-TXO-32CSMV-400-BN-TR; ECSTXO32CSMV400BNTR; Manufacturer_Part_Number ECS-TXO-32CSMV-400-BN-TR; Mouser Part Number 520-TXO32CSMV400BNTR

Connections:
+1V0: R111.1; also elsewhere on the board
+1V3: C49.1, C50.1, C51.1, C52.1, C53.1, C54.1, C55.1, C56.1, C57.1, C75.1, FB1.2, R109.1, U2.A7 (VDDA1P3_RX_TX), U2.A8 (VDDA1P3_RX_TX), U2.A9 (VDDA1P3_RX_TX), U2.A10 (VDDA1P3_RX_TX), U2.D2 (VDDA1P3_RX_RF), U2.D3 (VDDA1P3_RX_TX), U2.E3 (VDDA1P3_TX_LO_BUFFER), U2.F12 (VDDD1P3_DIG), U2.K4 (VDDA1P3_BB); also elsewhere on the board
+1V3SYNTH: C58.1, C59.1, C60.1, C61.1, C62.1, C63.1, C64.1, U2.B9 (VDDA1P3_TX_LO), U2.B10 (VDDA1P3_TX_VCO_LDO), U2.E2 (VDDA1P3_RX_LO), U2.F2 (VDDA1P3_RX_VCO_LDO), U2.J3 (VDDA1P3_RX_SYNTH), U2.K3 (VDDA1P3_TX_SYNTH); also elsewhere on the board
+1V3_SYNTH: R107.1
+1V3_TX: C69.1, C70.1, C71.1, C74.1, C319.1, C320.1, C321.1, FB1.1, L1.2, L2.2, L10.2, L11.2
+1V5: R105.1; also elsewhere on the board
+1V8: R113.1; also elsewhere on the board
/Transceiver/1V0_AD: IC15.4 (VIN6), R111.2, R112.1
/Transceiver/1V3S_AD: IC15.3 (VIN5), R107.2, R108.1
/Transceiver/1V3_AD: IC15.1 (VIN3), R109.2, R110.1
/Transceiver/1V5_AD: IC15.20 (VIN2), R105.2, R106.1
/Transceiver/1V8_AD: IC15.19 (VIN1), R113.2, R114.1
/Transceiver/2V5_AD: IC15.2 (VIN4), R115.2, R116.1
/Transceiver/3V3_AD: IC15.18 (VIN0), R103.2, R104.1
/Transceiver/RX1A_N: C73.1, U2.M2 (RX1A_N)
/Transceiver/RX1A_P: C72.1, U2.M1 (RX1A_P)
/Transceiver/RX1B_N: C323.1, U2.J1 (RX1B_N)
/Transceiver/RX1B_P: C322.1, U2.H1 (RX1B_P)
/Transceiver/TX1A_N: C67.1, C68.1, L1.1, L2.1, U2.M7 (TX1A_P), U2.M8 (TX1A_N)
/Transceiver/TX1B_N: C318.1, L11.1, U2.M10 (TX1B_N)
/Transceiver/TX1B_P: C317.1, L10.1, U2.M9 (TX1B_P)
AD_CI0: U2.C5 (CTRL_IN0); also elsewhere on the board
AD_CI1: U2.C6 (CTRL_IN1); also elsewhere on the board
AD_CI2: U2.D6 (CTRL_IN2); also elsewhere on the board
AD_CI3: U2.D5 (CTRL_IN3); also elsewhere on the board
AD_CLK_OUT: U2.J6 (CLK_OUT); also elsewhere on the board
AD_CO0: U2.D4 (CTRL_OUT0); also elsewhere on the board
AD_CO1: U2.E4 (CTRL_OUT1); also elsewhere on the board
AD_CO2: U2.E5 (CTRL_OUT2); also elsewhere on the board
AD_CO3: U2.E6 (CTRL_OUT3); also elsewhere on the board
AD_CO4: U2.F6 (CTRL_OUT4); also elsewhere on the board
AD_CO5: U2.F5 (CTRL_OUT5); also elsewhere on the board
AD_CO6: U2.F4 (CTRL_OUT6); also elsewhere on the board
AD_CO7: U2.G4 (CTRL_OUT7); also elsewhere on the board
AD_DATA_CLK_N: U2.H11 (DATA_CLK_N); also elsewhere on the board
AD_DATA_CLK_P: U2.G11 (DATA_CLK_P); also elsewhere on the board
AD_ENABLE: U2.G6 (ENABLE); also elsewhere on the board
AD_EN_AGC: U2.G5 (EN_AGC); also elsewhere on the board
AD_FB_CLK_N: U2.G10 (FB_CLK_N); also elsewhere on the board
AD_FB_CLK_P: U2.F10 (FB_CLK_P); also elsewhere on the board
AD_RESET: R15.2, U2.K5 (RESETB); also elsewhere on the board
AD_RX_D0_N: U2.K11 (P1_D0/RX_D0_N); also elsewhere on the board
AD_RX_D0_P: U2.J12 (P1_D1/RX_D0_P); also elsewhere on the board
AD_RX_D1_N: U2.K10 (P1_D2/RX_D1_N); also elsewhere on the board
AD_RX_D1_P: U2.J11 (P1_D3/RX_D1_P); also elsewhere on the board
AD_RX_D2_N: U2.K9 (P1_D4/RX_D2_N); also elsewhere on the board
AD_RX_D2_P: U2.J10 (P1_D5/RX_D2_P); also elsewhere on the board
AD_RX_D3_N: U2.K8 (P1_D6/RX_D3_N); also elsewhere on the board
AD_RX_D3_P: U2.J9 (P1_D7/RX_D3_P); also elsewhere on the board
AD_RX_D4_N: U2.K7 (P1_D8/RX_D4_N); also elsewhere on the board
AD_RX_D4_P: U2.J8 (P1_D9/RX_D4_P); also elsewhere on the board
AD_RX_D5_N: U2.J7 (P1_D10/RX_D5_N); also elsewhere on the board
AD_RX_D5_P: U2.H8 (P1_D11/RX_D5_P); also elsewhere on the board
AD_RX_FRA_N: U2.G7 (RX_FRAME_N); also elsewhere on the board
AD_RX_FRA_P: U2.G8 (RX_FRAME_P); also elsewhere on the board
AD_SCL: IC15.15 (SCL), IC16.6 (SCL); also elsewhere on the board
AD_SDA: IC15.14 (SDA), IC16.5 (SDA); also elsewhere on the board
AD_SPI_EN: U2.K6 (SPI_ENB); also elsewhere on the board
AD_SPI_MISO: U2.L6 (SPI_DO); also elsewhere on the board
AD_SPI_MOSI: U2.J4 (SPI_DI); also elsewhere on the board
AD_SPI_SCLK: U2.J5 (SPI_CLK); also elsewhere on the board
AD_SYNC_IN: U2.H5 (SYNC_IN); also elsewhere on the board
AD_TXNRX: U2.H4 (TXNRX); also elsewhere on the board
AD_TX_D0_N: U2.E12 (P0_D0/TX_D0_N); also elsewhere on the board
AD_TX_D0_P: U2.D11 (P0_D1/TX_D0_P); also elsewhere on the board
AD_TX_D1_N: U2.E11 (P0_D2/TX_D1_N); also elsewhere on the board
AD_TX_D1_P: U2.D10 (P0_D3/TX_D1_P); also elsewhere on the board
AD_TX_D2_N: U2.E10 (P0_D4/TX_D2_N); also elsewhere on the board
AD_TX_D2_P: U2.D9 (P0_D5/TX_D2_P); also elsewhere on the board
AD_TX_D3_N: U2.E9 (P0_D6/TX_D3_N); also elsewhere on the board
AD_TX_D3_P: U2.D8 (P0_D7/TX_D3_P); also elsewhere on the board
AD_TX_D4_N: U2.E8 (P0_D8/TX_D4_N); also elsewhere on the board
AD_TX_D4_P: U2.D7 (P0_D9/TX_D4_P); also elsewhere on the board
AD_TX_D5_N: U2.F8 (P0_D10/TX_D5_N); also elsewhere on the board
AD_TX_D5_P: U2.E7 (P0_D11/TX_D5_P); also elsewhere on the board
AD_TX_FRA_N: U2.H9 (TX_FRAME_N); also elsewhere on the board
AD_TX_FRA_P: U2.G9 (TX_FRAME_P); also elsewhere on the board
unnamed: C41.1, R21.2
unnamed: C48.1, R22.2
unnamed: C67.2, T1.6
unnamed: C68.2, T1.4
unnamed: C72.2, T3.6
unnamed: C73.2, T3.4
unnamed: C76.1, J4.1, R23.1
unnamed: C317.2, T2.6
unnamed: C318.2, T2.4
unnamed: C322.2, T4.6
unnamed: C323.2, T4.4
unnamed 335: D2.2, J7.1, T1.3; also elsewhere on the board
unnamed: D3.2, J2.1, T3.3
unnamed: D12.2, J9.1, L9.2, U10.3
unnamed: D13.2, J16.1, T4.3
unnamed: C303.1, C308.1, IC14.5 (VOUT), Y6.4 (VDD)
unnamed: IC15.11 (AS0), IC16.2 (E1)
unnamed: IC15.13 (AS1), IC16.1 (E0)
unnamed: C309.1, IC15.8 (DCAP)
unnamed: C310.1, IC15.7 (VREF)
unnamed: T2.3, U10.1
unnamed: R21.1, U2.G2 (RX_VCO_LDO_OUT), U2.G3 (VDDA1P1_RX_VCO)
unnamed: R22.1, U2.A11 (VDDA1P1_TX_VCO), U2.B11 (TX_VCO_LDO_OUT)
unnamed: C40.2, TP4.1, U2.B3 (AUXDAC1)
unnamed: R16.2, U2.L4 (RBIAS)
unnamed: C76.2, U2.M12 (XTALN), Y6.3 (OUTPUT)

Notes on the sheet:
RECIEVER
[4]
FPGA INTEFACE(LVDS_25)
DECOUPLING
[3]
[2]
POWER
TRANSMITTER
YOUR MISSING SOME MORE
[1]
References:
MISC.

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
Board: 6 copper layers, 546 parts (135 on the bottom side), 420 nets, no tracks yet.

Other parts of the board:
C116, C122, C124, C125, C126: 0.1uF; C_0402_1005Metric
C128: 1uF; C_0603_1608Metric
C242#2, C244#2: 4.7nF; C_0201_0603Metric
C243#2: 1.2nF; C_0201_0603Metric
C272, C275, C278, C281: 47uF; C_0805_2012Metric
C274, C277, C280, C283: 100nF; C_0402_1005Metric
L3: 43nH; L_0603_1608Metric
R98: 499R; R_0402_1005Metric
U6: PGA-102; SOT-89-3

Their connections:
+5V: C272.1, C274.2, C275.1, C277.2, C278.1, C280.2, C281.1, C283.2; also elsewhere on the board
/INTERFACES/MVDD: C116.2, C122.2, C124.2, C125.2, C126.2, C128.2; also elsewhere on the board
unnamed 335: L3.2, U6.3; also elsewhere on the board
SD_CD: R98.1; also elsewhere on the board

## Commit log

2026-05-05 Add README for Zynq-7020 SDR Carrier Board
    Add detailed project information for Zynq-7020 SDR Carrier Board including specifications, hardware design, and software tools.
2026-05-05 changed folder name
    [DDR.kicad_sch, FPGA.kicad_sch, GPIO.kicad_sch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]
